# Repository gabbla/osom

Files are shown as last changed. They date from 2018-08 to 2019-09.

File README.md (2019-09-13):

# **Open speedomenter** **WIP**

**OSOM** (read as _ˈôsəm_) is the acronym of Open Speedometer.

## Architecture
The new architecture is the following:

Clinet <==BLE==> Master <==2.4GHz==> Slave

where:
- Master: CC2541 <==UART==> PIC <==SPI==> nRF24L01+
- Slave:  PIC <==SPI==> nRF24L01+

The client is a device that must be compatible with BLE (Bluetooth 4.x).

The CC2541 (aka NP, aka Network Processor) will run a standard firmware that is in charge of providing a bluetooth connection to the PIC.

Master and Slave will exchange messages over a custom, light-weight, protocol.

## Specifications

- Microcontroller: PIC32MX274F256D @72MHz (TODO verify)
- Communication:
	- Bluetooth (master only): HM10 Bluetooth 4.2 Low Energy
	- Wireless: nRF24L01+ @2.4GHz
- Power: 
	- LiPo 1s Battery, 1200/2000 mAh (not choosen yet)
	- 5V provided by micro USB, 500 mA MAX
- Sensor: custom made 650nm modulated laser sensor 
- Laser source: Red diode laser, 650nm @5mW

## PIC PIN assignment

### Bluetooth (master only)

PIN|I/O|PPS|Function|Note
--|--|--|--|--|
6|IN|RPB2|U1RX|PIC <== NP
7|OUT|RPB3|U1TX|PIC ==> NP

### nRF24L01+

PIN|I/O|PPS|Function|Note
--|--|--|--|--|
21|IN|RPB10|INT1|Interrupt generated by nRF24L01+
22|OUT|RPB11|SDO2|
23|OUT|-|CS|RB12
24|IN|RPB13|SDI2|
25|OUT|-|CE|RB14
26|OUT|RPB15|SCK2|

### Debug

PIN|I/O|PPS|Function|Note
--|--|--|--|--|
4|OUT|RPB0|U2TX|PIC ==> PC
5|IN|RPB1|U2RX|PIC <== PC

USB will be available too, with at least a _comunication device class_ (CDC) enumeration. 

### Sensing

PIN|I/O|PPS|Function|Note
--|--|--|--|--|
16|IN|-|INT0|Left IN Interrupt
11|IN|RPB4|INT4|Right IN Interrupt

### Battery Charger

New PIC analisys required

### LEDs

Analisys required. 

**Note**
1. Master only: an extra LED from CC2541 indicates the BT connection status.
2. From the battery charger an extra LED indicates che charging status.

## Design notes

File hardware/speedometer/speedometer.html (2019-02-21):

Partlist exported from /home/italia.texa.org/gzampieri/projects/speedometer/hardware/speedometer/speedometer.sch at 21/02/19 17:55

Qty | Value | Device | Package | Parts | Description | ALLIED_NUMBER | ARROW_PART_NUMBER | ARROW_PRICE-STOCK | ARROW_PRICE/STOCK | DESCRIPTION | HEIGHT | MANUFACTURER_NAME | MANUFACTURER_PART_NUMBER | MF | MPN | OC_FARNELL | OC_NEWARK | RS | RS_PART_NUMBER | RS_PRICE-STOCK | RS_PRICE/STOCK | SPICEPREFIX | TP_SIGNAL_NAME
4 | | C-EUC0402K | C0402K | C18, C21, C22, C23 | CAPACITOR, European symbol | | | | | | | | | | | | | | | | | C
3 | | LED3MM | LED3MM | LED1, LED3, LED4 | LED
2 | | LEDCHIP-LED0805 | CHIP-LED0805 | LED5, LED6 | LED
1 | | LEDCHIPLED_0805 | CHIPLED_0805 | LED2 | LED
1 | | MA06-1 | MA06-1 | SV1 | PIN HEADER | | | | | | | | | | | unknown | unknown
4 | | MUN2214T1-NPN_DRIVER-SC59-BEC | SC59-BEC | T1, T2, T3, T4 | NPN Bias Resistor Transistor
1 | | PINHD-1X3 | 1X03 | JP1 | PIN HEADER
1 | | R-US_R0603 | R0603 | R17 | RESISTOR, American symbol | | | | | | | | | | | | | | | | | R
2 | 0 | R-US_R0402 | R0402 | R21, R22 | RESISTOR, American symbol | | | | | | | | | | | | | | | | | R
2 | 100 | R-US_R0603 | R0603 | R23, R24 | RESISTOR, American symbol | | | | | | | | | | | | | | 740-8978 | | | R
2 | 100k | R-US_R0603 | R0603 | R15, R20 | RESISTOR, American symbol | | | | | | | | | | | | | | | | | R
9 | 100n | C-EUC0603K | C0603K | C1, C2, C4, C5, C6, C7, C24, C27, C28 | CAPACITOR, European symbol | | | | | | | | | | | | | | | | | C
1 | 10104111-0001LF | 10104111-0001LF | MICRO_USB_A/B_TYPE_RECEPTACLE | J1 | FCI Right Angle SMT Female Type AB Version 2.0 Micro USB Connector, 100 V ac, 1.8A | 70236825 | | | | FCI Right Angle SMT Female Type AB Version 2.0 Micro USB Connector, 100 V ac, 1.8A | mm | FCI | 10104111-0001LF | | | | | | 1622014
7 | 10k | R-US_R0603 | R0603 | R4, R5, R12, R13, R14, R28, R35 | RESISTOR, American symbol | | | | | | | | | | | | | | | | | R
1 | 10m | R-US_R2512 | R2512 | R11 | RESISTOR, American symbol | | | | | | | | | | | | | 693-4381 | | | | R
1 | 10n | C-EUC0603K | C0603K | C13 | CAPACITOR, European symbol | | | | | | | | | | | | | | | | | C
10 | 10u | C-EUC0805K | C0805K | C3, C10, C11, C12, C25, C26, C29, C30, C31, C32 | CAPACITOR, European symbol | | | | | | | | | | | | | | | | | C
1 | 1k | R-US_R0603 | R0603 | R3 | RESISTOR, American symbol | | | | | | | | | | | | | | | | | R
5 | 1k5 | R-US_R0603 | R0603 | R1, R2, R16, R30, R36 | RESISTOR, American symbol | | | | | | | | | | | | | | | | | R
2 | 1n | C-EUC0603K | C0603K | C14, C15 | CAPACITOR, European symbol | | | | | | | | | | | | | | | | | C
1 | 1p | C-EUC0402K | C0402K | C20 | CAPACITOR, European symbol | | | | | | | | | | | | | | | | | C
1 | 1u | C-EUC0603K | C0603K | C8 | CAPACITOR, European symbol | | | | | | | | | | | | | | | | | C
1 | 22k | R-US_R0603 | R0603 | R19 | RESISTOR, American symbol | | | | | | | | | | | | | | | | | R
1 | 24LC024ST | 24LC024ST | TSSOP8 | IC9 | Serial EEPROM | | | | | | | | | | 24LC024H-I/ST | 1659745 | 77M3584
1 | 2n2 | C-EUC0402K | C0402K | C17 | CAPACITOR, European symbol | | | | | | | | | | | | | | | | | C
1 | 2n7 | INDUCTOR | C0402K | L2
1 | 33n | C-EUC0402K | C0402K | C16 | CAPACITOR, European symbol | | | | | | | | | | | | | | | | | C
1 | 3n9 | INDUCTOR | C0402K | L3
2 | 470 | R-US_R0603 | R0603 | R9, R10 | RESISTOR, American symbol | | | | | | | | | | | | | | | | | R
1 | 470n | C-EUC0603K | C0603K | C9 | CAPACITOR, European symbol | | | | | | | | | | | | | | | | | C
3 | 4k7 | R-US_R0603 | R0603 | R6, R7, R8 | RESISTOR, American symbol | | | | | | | | | | | | | | | | | R
1 | 4p7 | C-EUC0402K | C0402K | C19 | CAPACITOR, European symbol | | | | | | | | | | | | | | | | | C
1 | 74LVC1G32SE-7 | 74LVC1G32SE-7 | SOT353 | IC13
1 | 887 | R-US_R0603 | R0603 | R18 | RESISTOR, American symbol | | | | | | | | | | | | | 708-6111 | | | | R
1 | 8n2 | INDUCTOR | C0402K | L1
1 | BAT | B2B-PH-SM4-TB(LF)(SN) | B2B-PH-SM4-TB | J2 | Wire-To-Board Connector, PH Series, 2 Contacts, Header, 2 mm, Surface Mount, 1 Rows | | | | | Wire-To-Board Connector, PH Series, 2 Contacts, Header, 2 mm, Surface Mount, 1 Rows | mm | JST (JAPAN SOLDERLESS TERMINALS) | B2B-PH-SM4-TB(LF)(SN) | | | | | | 6881325P
1 | BQ24075RGTT | BQ24075RGTT | QFN50P300X300X80-17N | IC6 | 1.5A Li-Ion Charger, Power-Path VQFN16EP BQ24075RGTT, Battery Charge Controller, Lithium-Ion, 4500mA, 16-Pin QFN | | BQ24075RGTT | | https://www.arrow.com/en/products/bq24075rgtt/texas-instruments | 1.5A Li-Ion Charger, Power-Path VQFN16EP BQ24075RGTT, Battery Charge Controller, Lithium-Ion, 4500mA, 16-Pin QFN | 0.8mm | Texas Instruments | BQ24075RGTT | | | | | | 8175815P | | http://uk.rs-online.com/web/p/products/8175815P
1 | BQ27441DRZR-G1A | BQ27441DRZR-G1A | BQ27441DRZRG1A | IC5 | System-Side Impedance Track Battery Fuel (Gas) Gauge | | BQ27441DRZR-G1A | https://www.arrow.com/en/products/bq27441drzr-g1a/texas-instruments | | System-Side Impedance Track Battery Fuel (Gas) Gauge | mm | Texas Instruments | BQ27441DRZR-G1A
1 | CONUFL001-SMD-T | CONUFL001-SMD-T | CONUFL001-SMD | J3 | RF Connectors / Coaxial Connectors T&R U.FL Straight Surface Mount Jack | | CONUFL001-SMD-T | | | RF Connectors / Coaxial Connectors T&R U.FL Straight Surface Mount Jack | mm | Linx Technologies | CONUFL001-SMD-T
1 | CSTCE16M0V53-R0 | CSTCE12M0G15L99-R0 | CSTCE_G | IC8 | CSTCE12M0G15L99-R0, Ceramic Resonator, 12MHz Shear 33pF, 3-Pin SMT, 3.2 x 1.3 x 0.7mm | | CSTCE12M0G15L99-R0 | | https://www.arrow.com/en/products/cstce12m0g15l99-r0/murata-manufacturing | CSTCE12M0G15L99-R0, Ceramic Resonator, 12MHz Shear 33pF, 3-Pin SMT, 3.2 x 1.3 x 0.7mm | mm | Murata Electronics | CSTCE12M0G15L99-R0 | | | | | | 7926527P | | http://uk.rs-online.com/web/p/products/7926527P
1 | CSTCE8M00G55-R0 | CSTCE12M0G15L99-R0 | CSTCE_G | IC3 | CSTCE12M0G15L99-R0, Ceramic Resonator, 12MHz Shear 33pF, 3-Pin SMT, 3.2 x 1.3 x 0.7mm | | CSTCE12M0G15L99-R0 | | https://www.arrow.com/en/products/cstce12m0g15l99-r0/murata-manufacturing | CSTCE12M0G15L99-R0, Ceramic Resonator, 12MHz Shear 33pF, 3-Pin SMT, 3.2 x 1.3 x 0.7mm | mm | Murata Electronics | CSTCE12M0G15L99-R0 | | | | | | 7926527P | | http://uk.rs-online.com/web/p/products/7926527P
1 | HM-11 | HM-11 | HM-11 | IC4 | JNHuaMao HM-11 Bluetooth 4.0 Transceiver
1 | Left | B2B-XH-A(LF)(SN) | SHDR2W64P0X250_1X2_740X575X700 | J7 | JST XH Series, 2.5mm Pitch 2 Way 1 Row Straight PCB Header, Solder Termination, 3A | | B2B-XH-A(LF)(SN) | | https://www.arrow.com/en/products/b2b-xh-a-lf-sn/jst-manufacturing | JST XH Series, 2.5mm Pitch 2 Way 1 Row Straight PCB Header, Solder Termination, 3A | 7mm | JST (JAPAN SOLDERLESS TERMINALS) | B2B-XH-A(LF)(SN) | | | | | | 1667312 | | http://uk.rs-online.com/web/p/products/1667312
1 | Left_sens | B4B-XH-A(LF)(SN) | SHDR4W64P0X250_1X4_1240X575X70 | J6 | XH-2.5mm Header top entry 4 way JST XH Series, Series Number B4B, 2.5mm Pitch 4 Way 1 Row Straight PCB Header, Solder Termination, 3A | | B4B-XH-A(LF)(SN) | | https://www.arrow.com/en/products/b4b-xh-a-lf-sn/jst-manufacturing | XH-2.5mm Header top entry 4 way JST XH Series, Series Number B4B, 2.5mm Pitch 4 Way 1 Row Straight PCB Header, Solder Termination, 3A | 7mm | JST (JAPAN SOLDERLESS TERMINALS) | B4B-XH-A(LF)(SN) | | | | | | 1724913 | | http://uk.rs-online.com/web/p/products/1724913 | E
1 | M310210 | M310210 | M310210 | ANT1
1 | MAX16054AZT+T | MAX16054AZT+T | SOT95P275X110-6N | IC10 | On Off Controller, Debounce, 15kV ESD MAX16054AZT+T, Voltage Supervisor No Push Button Controller 6-Pin SOT-23 | | MAX16054AZT+T | | http://uk.rs-online.com/web/p/products/9237416 | On Off Controller, Debounce, 15kV ESD MAX16054AZT+T, Voltage Supervisor No Push Button Controller 6-Pin SOT-23 | 1.1mm | Maxim Integrated | MAX16054AZT+T | | | | | | 9237416 | | http://uk.rs-online.com/web/p/products/9237416
1 | NRF24L01P-T | NRF24L01P-T | QFN50P400X400X95-21N | IC7 | RF Transceiver IC 2.4GHz ISM Band QFN20 Nordic Semiconductor NRF24L01P-T, RF Transceiver 2400MHz to 2483.5MHz 1.9 3.6 V 20-Pin QFN | | nRF24L01P-T | | https://www.arrow.com/en/products/nrf24l01p-t/nordic-semiconductor | RF Transceiver IC 2.4GHz ISM Band QFN20 Nordic Semiconductor NRF24L01P-T, RF Transceiver 2400MHz to 2483.5MHz 1.9 3.6 V 20-Pin QFN | 0.95mm | Nordic Semiconductor | nRF24L01P-T | | | | | | 8855748P | | http://uk.rs-online.com/web/p/products/8855748P
1 | PIC32MX274F256DT-I_PT | PIC32MX274F256DT-I_PT | QFP80P1200X1200X120-44N | IC1 | 32-bit Microcontrollers - MCU 256KB Flash, 64KB RAM, 10-Bit ADC, UART, SPI/I2S, I2C + VBATT Pin, USB | | PIC32MX274F256DT-I/PT | | | 32-bit Microcontrollers - MCU 256KB Flash, 64KB RAM, 10-Bit ADC, UART, SPI/I2S, I2C + VBATT Pin, USB | 1.2mm | Microchip | PIC32MX274F256DT-I/PT
1 | PTS645VJM61LFS | PTS645VJM61LFS | PTS645VJM61LFS | S1 | Tactile Switches Tact | | PTS645VJM61LFS | | | Tactile Switches Tact | 7mm | C & K COMPONENTS | PTS645VJM61LFS
1 | Right | B2B-XH-A(LF)(SN) | SHDR2W64P0X250_1X2_740X575X700 | J5 | JST XH Series, 2.5mm Pitch 2 Way 1 Row Straight PCB Header, Solder Termination, 3A | | B2B-XH-A(LF)(SN) | | https://www.arrow.com/en/products/b2b-xh-a-lf-sn/jst-manufacturing | JST XH Series, 2.5mm Pitch 2 Way 1 Row Straight PCB Header, Solder Termination, 3A | 7mm | JST (JAPAN SOLDERLESS TERMINALS) | B2B-XH-A(LF)(SN) | | | | | | 1667312 | | http://uk.rs-online.com/web/p/products/1667312
1 | Right_sens | B4B-XH-A(LF)(SN) | SHDR4W64P0X250_1X4_1240X575X70 | J4 | XH-2.5mm Header top entry 4 way JST XH Series, Series Number B4B, 2.5mm Pitch 4 Way 1 Row Straight PCB Header, Solder Termination, 3A | | B4B-XH-A(LF)(SN) | | https://www.arrow.com/en/products/b4b-xh-a-lf-sn/jst-manufacturing | XH-2.5mm Header top entry 4 way JST XH Series, Series Number B4B, 2.5mm Pitch 4 Way 1 Row Straight PCB Header, Solder Termination, 3A | 7mm | JST (JAPAN SOLDERLESS TERMINALS) | B4B-XH-A(LF)(SN) | | | | | | 1724913 | | http://uk.rs-online.com/web/p/products/1724913
1 | SN65220DBVRG4 | SN65220DBVRG4 | SOT95P280X145-6N | IC2 | ESD Suppressors / TVS Diodes Sngl Port Transient Suppressor | | SN65220DBVRG4 | | https://www.arrow.com/en/products/sn65220dbvrg4/texas-instruments | ESD Suppressors / TVS Diodes Sngl Port Transient Suppressor | 1.45mm | Texas Instruments | SN65220DBVRG4
2 | SN74AHC1G08DBVR | SN74AHC1G08DBVR | SOT95P280X145-5N | U1, U2 | Texas Instruments SN74AHC1G08DBVR, 2-Input AND Logic Gate, 2 5.5 V, 5-Pin SOT-23 | | SN74AHC1G08DBVR | https://www.arrow.com/en/products/sn74ahc1g08dbvr/texas-instruments | | Texas Instruments SN74AHC1G08DBVR, 2-Input AND Logic Gate, 2 5.5 V, 5-Pin SOT-23 | 1.45mm | Texas Instruments | SN74AHC1G08DBVR | | | | | | 1218343 | http://uk.rs-online.com/web/p/products/1218343
1 | TPB1,27 | TPB1,27 | B1,27 | TP12 | Test pad | | | | | | | | | | | | | | | | | | BT_KEY
1 | TPB1,27 | TPB1,27 | B1,27 | TP11 | Test pad | | | | | | | | | | | | | | | | | | BT_RST
1 | TPB1,27 | TPB1,27 | B1,27 | TP10 | Test pad | | | | | | | | | | | | | | | | | | BT_RX
1 | TPB1,27 | TPB1,27 | B1,27 | TP9 | Test pad | | | | | | | | | | | | | | | | | | BT_TX
1 | TPB1,27 | TPB1,27 | B1,27 | TP17 | Test pad | | | | | | | | | | | | | | | | | | TP_!CHG
1 | TPB1,27 | TPB1,27 | B1,27 | TP16 | Test pad | | | | | | | | | | | | | | | | | | TP_!PGOOD
1 | TPB1,27 | TPB1,27 | B1,27 | TP22 | Test pad | | | | | | | | | | | | | | | | | | TP_3V3
1 | TPB1,27 | TPB1,27 | B1,27 | TP23 | Test pad | | | | | | | | | | | | | | | | | | TP_5V
1 | TPB1,27 | TPB1,27 | B1,27 | TP13 | Test pad | | | | | | | | | | | | | | | | | | TP_BAT
1 | TPB1,27 | TPB1,27 | B1,27 | TP14 | Test pad | | | | | | | | | | | | | | | | | | TP_BAT2
1 | TPB1,27 | TPB1,27 | B1,27 | TP18 | Test pad | | | | | | | | | | | | | | | | | | TP_GND
2 | TPB1,27 | TPB1,27 | B1,27 | TP25, TP26 | Test pad | | | | | | | | | | | | | | | | | | TP_L_DX
1 | TPB1,27 | TPB1,27 | B1,27 | TP8 | Test pad | | | | | | | | | | | | | | | | | | TP_NRF_CE
1 | TPB1,27 | TPB1,27 | B1,27 | TP6 | Test pad | | | | | | | | | | | | | | | | | | TP_NRF_CS
1 | TPB1,27 | TPB1,27 | B1,27 | TP5 | Test pad | | | | | | | | | | | | | | | | | | TP_NRF_IRQ
1 | TPB1,27 | TPB1,27 | B1,27 | TP1 | Test pad | | | | | | | | | | | | | | | | | | TP_SCL
1 | TPB1,27 | TPB1,27 | B1,27 | TP2 | Test pad | | | | | | | | | | | | | | | | | | TP_SDA
1 | TPB1,27 | TPB1,27 | B1,27 | TP7 | Test pad | | | | | | | | | | | | | | | | | | TP_SPI1_SCK
1 | TPB1,27 | TPB1,27 | B1,27 | TP4 | Test pad | | | | | | | | | | | | | | | | | | TP_SPI1_SDI
1 | TPB1,27 | TPB1,27 | B1,27 | TP3 | Test pad | | | | | | | | | | | | | | | | | | TP_SPI1_SDO
1 | TPB1,27 | TPB1,27 | B1,27 | TP24 | Test pad | | | | | | | | | | | | | | | | | | TP_SYS_EN
1 | TPB1,27 | TPB1,27 | B1,27 | TP21 | Test pad | | | | | | | | | | | | | | | | | | TP_SYS_EN_MAX
1 | TPB1,27 | TPB1,27 | B1,27 | TP20 | Test pad | | | | | | | | | | | | | | | | | | TP_SYS_EN_PIC
1 | TPB1,27 | TPB1,27 | B1,27 | TP19 | Test pad | | | | | | | | | | | | | | | | | | TP_VCCINT
1 | TPB1,27 | TPB1,27 | B1,27 | TP15 | Test pad | | | | | | | | | | | | | | | | | | TP_VUSB
1 | TPS63001DRCT | TPS63000DRCT | SON50P300X300X100-11N | IC11 | TPS63000DRCT Buck/Boost Converter, 1.2A, Adjustable, 1.2 5.5 V, 1500 kHz, 10-Pin SON EP | | TPS63000DRCT | | https://www.arrow.com/en/products/tps63000drct/texas-instruments | TPS63000DRCT Buck/Boost Converter, 1.2A, Adjustable, 1.2 5.5 V, 1500 kHz, 10-Pin SON EP | 1mm | Texas Instruments | TPS63000DRCT | | | | | | 0389334P | | http://uk.rs-online.com/web/p/products/0389334P
1 | TPS63002DRCT | TPS63000DRCT | SON50P300X300X100-11N | IC12 | TPS63000DRCT Buck/Boost Converter, 1.2A, Adjustable, 1.2 5.5 V, 1500 kHz, 10-Pin SON EP | | TPS63000DRCT | | https://www.arrow.com/en/products/tps63000drct/texas-instruments | TPS63000DRCT Buck/Boost Converter, 1.2A, Adjustable, 1.2 5.5 V, 1500 kHz, 10-Pin SON EP | 1mm | Texas Instruments | TPS63000DRCT | | | | | | 0389334P | | http://uk.rs-online.com/web/p/products/0389334P
2 | TSW-102-07-G-S | TSW-102-07-G-S | TSW-102-XX-G-S | X1, X2 | THROUGH-HOLE .025" SQ POST HEADER | | | | | | | | | Samtec Inc. | TSW-102-07-G-S
2 | VLF4012AT-2R2M1R5 | LPS3015-222MRB | LPS3015 | L4, L5 | COILCRAFT - LPS3015-222MRB - INDUCTOR, SHLD, 2.2UH, 20%, 1.1A, SMD | | LPS3015-222MRB | | | COILCRAFT - LPS3015-222MRB - INDUCTOR, SHLD, 2.2UH, 20%, 1.1A, SMD | mm | COILCRAFT | LPS3015-222MRB | | | | | | 644-1952

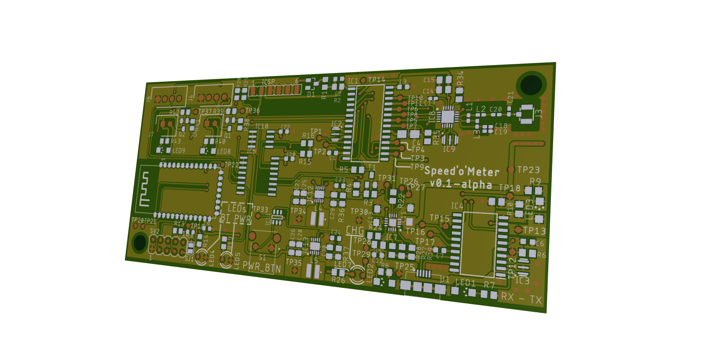
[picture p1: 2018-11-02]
images/speedometer_v_0_1_alpha.png

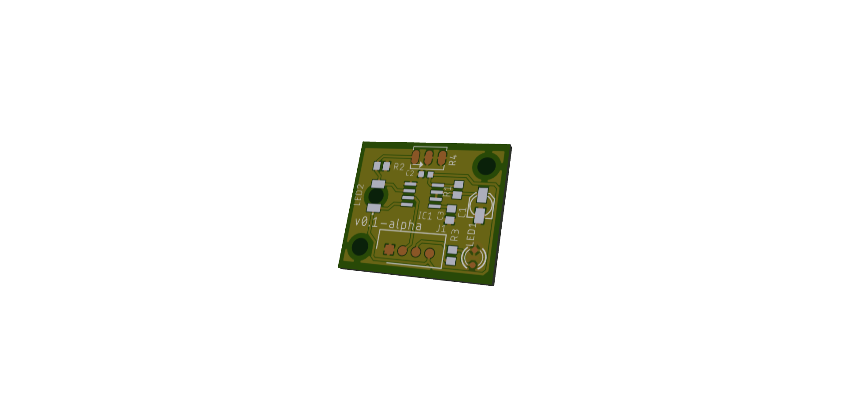
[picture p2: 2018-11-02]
images/laser_sensor_v_0_1_alpha.png

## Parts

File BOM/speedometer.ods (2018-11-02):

Qty | Value | Device | Package | Parts | Description | ALLIED_NUMBER | ALLIED_PRICE/STOCK | ARROW_PART_NUMBER | ARROW_PRICE/STOCK | DESCRIPTION | HEIGHT | MANUFACTURER_NAME | MANUFACTURER_PART_NUMBER | MF | MPN | OC_FARNELL | OC_NEWARK | RS | RS_PART_NUMBER | RS_PRICE/STOCK | SPICEPREFIX | TP_SIGNAL_NAME
1 | microUSB | 10104111-0001LF | MICRO_USB_A/B_TYPE_RECEPTACLE | J1 | FCI Right Angle SMT Female Type AB Version 2.0 Micro USB Connector, 100 V ac, 1.8A | 70236825 |  |  |  | FCI Right Angle SMT Female Type AB Version 2.0 Micro USB Connector, 100 V ac, 1.8A | mm | FCI | 10104111-0001LF |  |  |  |  |  | 1622014
1 | 24LC024SN | 24LC024SN | SO-08 | IC10 | Serial EEPROM |  |  |  |  |  |  |  |  | MICROCHIP | 24LC024/SN | 1659744 | 92C7092
1 | BAT | B2B-PH-SM4-TB(LF)(SN) | B2B-PH-SM4-TB | J2 | Wire-To-Board Connector, PH Series, 2 Contacts, Header, 2 mm, Surface Mount, 1 Rows |  |  |  |  | Wire-To-Board Connector, PH Series, 2 Contacts, Header, 2 mm, Surface Mount, 1 Rows | mm | JST (JAPAN SOLDERLESS TERMINALS) | B2B-PH-SM4-TB(LF)(SN) |  |  |  |  |  | 6881325P
1 | Left | B2B-XH-A(LF)(SN) | SHDR2W64P0X250_1X2_740X575X700 | J7 | JST XH Series, 2.5mm Pitch 2 Way 1 Row Straight PCB Header, Solder Termination, 3A |  |  | B2B-XH-A(LF)(SN) | https://www.arrow.com/en/products/b2b-xh-a-lf-sn/jst-manufacturing | JST XH Series, 2.5mm Pitch 2 Way 1 Row Straight PCB Header, Solder Termination, 3A | 7mm | JST (JAPAN SOLDERLESS TERMINALS) | B2B-XH-A(LF)(SN) |  |  |  |  |  | 1667312 | http://uk.rs-online.com/web/p/products/1667312 | B
1 | Right | B2B-XH-A(LF)(SN) | SHDR2W64P0X250_1X2_740X575X700 | J5 | JST XH Series, 2.5mm Pitch 2 Way 1 Row Straight PCB Header, Solder Termination, 3A |  |  | B2B-XH-A(LF)(SN) | https://www.arrow.com/en/products/b2b-xh-a-lf-sn/jst-manufacturing | JST XH Series, 2.5mm Pitch 2 Way 1 Row Straight PCB Header, Solder Termination, 3A | 7mm | JST (JAPAN SOLDERLESS TERMINALS) | B2B-XH-A(LF)(SN) |  |  |  |  |  | 1667312 | http://uk.rs-online.com/web/p/products/1667312
1 | Left_sens | B4B-XH-A(LF)(SN) | SHDR4W64P0X250_1X4_1240X575X70 | J6 | XH-2.5mm Header top entry 4 way JST XH Series, Series Number B4B, 2.5mm Pitch 4 Way 1 Row Straight PCB Header, Solder Termination, 3A |  |  | B4B-XH-A(LF)(SN) | https://www.arrow.com/en/products/b4b-xh-a-lf-sn/jst-manufacturing | XH-2.5mm Header top entry 4 way JST XH Series, Series Number B4B, 2.5mm Pitch 4 Way 1 Row Straight PCB Header, Solder Termination, 3A | 7mm | JST (JAPAN SOLDERLESS TERMINALS) | B4B-XH-A(LF)(SN) |  |  |  |  |  | 1724913 | http://uk.rs-online.com/web/p/products/1724913 | E
1 | Right_sens | B4B-XH-A(LF)(SN) | SHDR4W64P0X250_1X4_1240X575X70 | J4 | XH-2.5mm Header top entry 4 way JST XH Series, Series Number B4B, 2.5mm Pitch 4 Way 1 Row Straight PCB Header, Solder Termination, 3A |  |  | B4B-XH-A(LF)(SN) | https://www.arrow.com/en/products/b4b-xh-a-lf-sn/jst-manufacturing | XH-2.5mm Header top entry 4 way JST XH Series, Series Number B4B, 2.5mm Pitch 4 Way 1 Row Straight PCB Header, Solder Termination, 3A | 7mm | JST (JAPAN SOLDERLESS TERMINALS) | B4B-XH-A(LF)(SN) |  |  |  |  |  | 1724913 | http://uk.rs-online.com/web/p/products/1724913
1 | BAT54 | BAT54 | SOT23 | D1 | Schottky Diodes
2 | BC817 | BC817-16LT1SMD | SOT23-BEC | Q1, Q3 | NPN Transistor
2 | BC817 | BC817-16LT1SMD | SOT23-BEC | Q2, Q4 | NPN Transistor |  |  |  |  |  |  |  |  |  |  |  |  |  |  |  | Q
1 | BC817-16LT1SMD | BC817-16LT1SMD | SOT23-BEC | T1 | NPN Transistor
1 | BQ24075RGTT | BQ24075RGTT | QFN50P300X300X80-17N | IC7 | 1.5A Li-Ion Charger, Power-Path VQFN16EP BQ24075RGTT, Battery Charge Controller, Lithium-Ion, 4500mA, 16-Pin QFN |  |  | BQ24075RGTT | https://www.arrow.com/en/products/bq24075rgtt/texas-instruments | 1.5A Li-Ion Charger, Power-Path VQFN16EP BQ24075RGTT, Battery Charge Controller, Lithium-Ion, 4500mA, 16-Pin QFN | 0.8mm | Texas Instruments | BQ24075RGTT |  |  |  |  |  | 8175815P | http://uk.rs-online.com/web/p/products/8175815P
1 | 1p | C-EUC0402K | C0402K | C21 | CAPACITOR, European symbol |  |  |  |  |  |  |  |  |  |  |  |  |  |  |  | C
1 | 1p5 | C-EUC0402K | C0402K | C20 | CAPACITOR, European symbol |  |  |  |  |  |  |  |  |  |  |  |  |  |  |  | C
1 | 2n2 | C-EUC0402K | C0402K | C18 | CAPACITOR, European symbol |  |  |  |  |  |  |  |  |  |  |  |  |  |  |  | C
1 | 33n | C-EUC0402K | C0402K | C17 | CAPACITOR, European symbol |  |  |  |  |  |  |  |  |  |  |  |  |  |  |  | C
1 | 4p7 | C-EUC0402K | C0402K | C19 | CAPACITOR, European symbol |  |  |  |  |  |  |  |  |  |  |  |  |  |  |  | C
12 | 100n | C-EUC0603K | C0603K | C1, C2, C3, C6, C7, C8, C9, C10, C12, C22, C23, C24 | CAPACITOR, European symbol |  |  |  |  |  |  |  |  |  |  |  |  |  |  |  | C
1 | 10n | C-EUC0805K | C0805K | C14 | CAPACITOR, European symbol |  |  |  |  |  |  |  |  |  |  |  |  |  |  |  | C
6 | 10u | C-EUC0805K | C0805K | C25, C26, C27, C28, C29, C30 | CAPACITOR, European symbol |  |  |  |  |  |  |  |  |  |  |  |  |  |  |  | C
1 | 1n | C-EUC0805K | C0805K | C15 | CAPACITOR, European symbol |  |  |  |  |  |  |  |  |  |  |  |  |  |  |  | C
1 | 4u7 | C-EUC0805K | C0805K | C5 | CAPACITOR, European symbol |  |  |  |  |  |  |  |  |  |  |  |  |  |  |  | C
1 | CONUFL001-SMD-T | CONUFL001-SMD-T | CONUFL001-SMD | J3 | RF Connectors / Coaxial Connectors T&R U.FL Straight Surface Mount Jack |  |  | CONUFL001-SMD-T |  | RF Connectors / Coaxial Connectors T&R U.FL Straight Surface Mount Jack | mm | Linx Technologies | CONUFL001-SMD-T
1 | 10u | CPOL-EUA/3216-18W | A/3216-18W | C4 | POLARIZED CAPACITOR, European symbol |  |  |  |  |  |  |  |  |  |  |  |  | 501-9324 |  |  | C
2 | 4u7 | CPOL-EUSMCA | SMC_A | C11, C13 | POLARIZED CAPACITOR, European symbol |  |  |  |  |  |  |  |  |  |  |  |  |  |  |  | C
1 | CSTCE12M0G15L99-R0 | CSTCE12M0G15L99-R0 | CSTCE_G | IC3 | CSTCE12M0G15L99-R0, Ceramic Resonator, 12MHz Shear 33pF, 3-Pin SMT, 3.2 x 1.3 x 0.7mm |  |  | CSTCE12M0G15L99-R0 | https://www.arrow.com/en/products/cstce12m0g15l99-r0/murata-manufacturing | CSTCE12M0G15L99-R0, Ceramic Resonator, 12MHz Shear 33pF, 3-Pin SMT, 3.2 x 1.3 x 0.7mm | mm | Murata Electronics | CSTCE12M0G15L99-R0 |  |  |  |  |  | 7926527P | http://uk.rs-online.com/web/p/products/7926527P
1 | CSTCE16M0V53-R0 | CSTCE12M0G15L99-R0 | CSTCE_G | IC9 | CSTCE12M0G15L99-R0, Ceramic Resonator, 12MHz Shear 33pF, 3-Pin SMT, 3.2 x 1.3 x 0.7mm |  |  | CSTCE12M0G15L99-R0 | https://www.arrow.com/en/products/cstce12m0g15l99-r0/murata-manufacturing | CSTCE12M0G15L99-R0, Ceramic Resonator, 12MHz Shear 33pF, 3-Pin SMT, 3.2 x 1.3 x 0.7mm | mm | Murata Electronics | CSTCE12M0G15L99-R0 |  |  |  |  |  | 7926527P | http://uk.rs-online.com/web/p/products/7926527P
1 | CSTCE8M00G55-R0 | CSTCE12M0G15L99-R0 | CSTCE_G | IC2 | CSTCE12M0G15L99-R0, Ceramic Resonator, 12MHz Shear 33pF, 3-Pin SMT, 3.2 x 1.3 x 0.7mm |  |  | CSTCE12M0G15L99-R0 | https://www.arrow.com/en/products/cstce12m0g15l99-r0/murata-manufacturing | CSTCE12M0G15L99-R0, Ceramic Resonator, 12MHz Shear 33pF, 3-Pin SMT, 3.2 x 1.3 x 0.7mm | mm | Murata Electronics | CSTCE12M0G15L99-R0 |  |  |  |  |  | 7926527P | http://uk.rs-online.com/web/p/products/7926527P
1 |  | FE06-1 | FE06 | ICSP | FEMALE HEADER |  |  |  |  |  |  |  |  |  |  | unknown | unknown
1 | HM-10 | HM-10 | HM-10 | U1
1 | 2n7 | INDUCTOR | C0402K | L3
1 | 3n9 | INDUCTOR | C0402K | L2
1 | 8n2 | INDUCTOR | C0402K | L1
1 |  | LED3MM | LED3MM | LED7 | LED
1 | Blue | LED3MM | LED3MM | LED4 | LED
1 | Red | LED3MM | LED3MM | LED5 | LED
1 |  | LEDCHIPLED_1206 | CHIPLED_1206 | LED8 | LED
1 |  | LEDCHIPLED_1206 | CHIPLED_1206 | LED9 | LED |  |  |  |  |  |  |  |  |  |  |  |  |  |  |  | L
1 | Blue | LEDCHIPLED_1206 | CHIPLED_1206 | LED3 | LED
1 | Green | LEDCHIPLED_1206 | CHIPLED_1206 | LED1 | LED
1 | Red | LEDCHIPLED_1206 | CHIPLED_1206 | LED2 | LED
1 |  | MA05-2 | MA05-2 | SV2 | PIN HEADER |  |  |  |  |  |  |  |  |  |  | unknown | unknown
1 | MAX16054AZT+T | MAX16054AZT+T | SOT95P275X110-6N | IC11 | On Off Controller, Debounce, 15kV ESD MAX16054AZT+T, Voltage Supervisor No Push Button Controller 6-Pin SOT-23 |  |  | MAX16054AZT+T | http://uk.rs-online.com/web/p/products/9237416 | On Off Controller, Debounce, 15kV ESD MAX16054AZT+T, Voltage Supervisor No Push Button Controller 6-Pin SOT-23 | 1.1mm | Maxim Integrated | MAX16054AZT+T |  |  |  |  |  | 9237416 | http://uk.rs-online.com/web/p/products/9237416
1 | MCP2200-I_SO | MCP2200-I_SO | SOIC127P1030X265-20N | IC4 | USB 2.0 to serial UART converter w/ GPIO | 70047463 | http://www.alliedelec.com/microchip-technology-inc-mcp2200-i-so/70047463/ | MCP2200-I/SO | https://www.arrow.com/en/products/mcp2200-iso/microchip-technology | USB 2.0 to serial UART converter w/ GPIO | 2.65mm | Microchip | MCP2200-I/SO |  |  |  |  |  | 6988993P | http://uk.rs-online.com/web/p/products/6988993P
1 | NRF24L01P-T | NRF24L01P-T | QFN50P400X400X95-21N | IC8 | RF Transceiver IC 2.4GHz ISM Band QFN20 Nordic Semiconductor NRF24L01P-T, RF Transceiver 2400MHz to 2483.5MHz 1.9 3.6 V 20-Pin QFN |  |  | nRF24L01P-T | https://www.arrow.com/en/products/nrf24l01p-t/nordic-semiconductor | RF Transceiver IC 2.4GHz ISM Band QFN20 Nordic Semiconductor NRF24L01P-T, RF Transceiver 2400MHz to 2483.5MHz 1.9 3.6 V 20-Pin QFN | 0.95mm | Nordic Semiconductor | nRF24L01P-T |  |  |  |  |  | 8855748P | http://uk.rs-online.com/web/p/products/8855748P
1 | PCF8574T | PCF8574T | SO16W | IC6 | I2C-Bus Remote 8-bit I/O expander |  |  |  |  |  |  |  |  |  | PCF8574T/3,512 | 1201255 | 70R6870
1 | PIC32MX110F016B-I_SO | PIC32MX110F016B-I_SO | SOIC127P1030X265-28N | IC1 | 32-bit Microcontrollers (up to 256 KB Flash and 64 KB SRAM) with Audio and Graphics Interfaces, USB, and Advanced Analog | 70452123 | http://www.alliedelec.com/microchip-technology-inc-pic32mx110f016b-i-so/70452123/ | PIC32MX110F016B-I/SO | https://www.arrow.com/en/products/pic32mx110f016b-iso/microchip-technology | 32-bit Microcontrollers (up to 256 KB Flash and 64 KB SRAM) with Audio and Graphics Interfaces, USB, and Advanced Analog | 2.65mm | Microchip | PIC32MX110F016B-I/SO
1 | PTS645VJM61LFS | PTS645VJM61LFS | PTS645VJM61LFS | S1 | Tactile Switches Tact |  |  | PTS645VJM61LFS |  | Tactile Switches Tact | 7mm | C & K COMPONENTS | PTS645VJM61LFS
1 |  | R-US_R0805 | R0805 | R17 | RESISTOR, American symbol
1 |  | R-US_R0805 | R0805 | R24 | RESISTOR, American symbol |  |  |  |  |  |  |  |  |  |  |  |  |  |  |  | R
2 | 100 | R-US_R0805 | R0805 | R36, R37 | RESISTOR, American symbol |  |  |  |  |  |  |  |  |  |  |  |  |  | 740-8978 |  | R
7 | 100k | R-US_R0805 | R0805 | R4, R18, R22, R23, R35, R39, R42 | RESISTOR, American symbol |  |  |  |  |  |  |  |  |  |  |  |  |  |  |  | R
13 | 10k | R-US_R0805 | R0805 | R1, R3, R5, R12, R13, R15, R16, R19, R20, R21, R25, R38, R41 | RESISTOR, American symbol |  |  |  |  |  |  |  |  |  |  |  |  |  |  |  | R
1 | 18k | R-US_R0805 | R0805 | R10 | RESISTOR, American symbol |  |  |  |  |  |  |  |  |  |  |  |  |  |  |  | R
1 | 1k | R-US_R0805 | R0805 | R2 | RESISTOR, American symbol |  |  |  |  |  |  |  |  |  |  |  |  |  |  |  | R
3 | 1k5 | R-US_R0805 | R0805 | R26, R40, R43 | RESISTOR, American symbol |  |  |  |  |  |  |  |  |  |  |  |  |  |  |  | R
1 | 22k | R-US_R0805 | R0805 | R34 | RESISTOR, American symbol |  |  |  |  |  |  |  |  |  |  |  |  |  |  |  | R
1 | 39k | R-US_R0805 | R0805 | R11 | RESISTOR, American symbol |  |  |  |  |  |  |  |  |  |  |  |  |  |  |  | R
1 | 4k7 | R-US_R0805 | R0805 | R6 | RESISTOR, American symbol |  |  |  |  |  |  |  |  |  |  |  |  |  |  |  | R
1 | 620 | R-US_R0805 | R0805 | R14 | RESISTOR, American symbol
3 | 620 | R-US_R0805 | R0805 | R7, R8, R9 | RESISTOR, American symbol |  |  |  |  |  |  |  |  |  |  |  |  |  |  |  | R
1 | 887 | R-US_R0805 | R0805 | R27 | RESISTOR, American symbol |  |  |  |  |  |  |  |  |  |  |  |  | 708-6111 |  |  | R
1 | TBD | R-US_R0805 | R0805 | R28 | RESISTOR, American symbol |  |  |  |  |  |  |  |  |  |  |  |  | 708-6111 |  |  | R
1 | TPS63001DRCT | TPS63000DRCT | SON50P300X300X100-11N | IC12 | TPS63000DRCT Buck/Boost Converter, 1.2A, Adjustable, 1.2 5.5 V, 1500 kHz, 10-Pin SON EP |  |  | TPS63000DRCT | https://www.arrow.com/en/products/tps63000drct/texas-instruments | TPS63000DRCT Buck/Boost Converter, 1.2A, Adjustable, 1.2 5.5 V, 1500 kHz, 10-Pin SON EP | 1mm | Texas Instruments | TPS63000DRCT |  |  |  |  |  | 0389334P | http://uk.rs-online.com/web/p/products/0389334P
1 | TPS63002DRCT | TPS63000DRCT | SON50P300X300X100-11N | IC13 | TPS63000DRCT Buck/Boost Converter, 1.2A, Adjustable, 1.2 5.5 V, 1500 kHz, 10-Pin SON EP |  |  | TPS63000DRCT | https://www.arrow.com/en/products/tps63000drct/texas-instruments | TPS63000DRCT Buck/Boost Converter, 1.2A, Adjustable, 1.2 5.5 V, 1500 kHz, 10-Pin SON EP | 1mm | Texas Instruments | TPS63000DRCT |  |  |  |  |  | 0389334P | http://uk.rs-online.com/web/p/products/0389334P
2 | VLF4012AT-2R2M1R5 | VLF4012AT-3R3M1R3 | VLF4012A | L4, L5 | Fixed Inductors 3.3uH 1.3A 4x4x1.2mm |  |  | VLF4012AT-3R3M1R3 | https://www.arrow.com/en/products/vlf4012at-3r3m1r3/tdk | Fixed Inductors 3.3uH 1.3A 4x4x1.2mm | mm | TDK | VLF4012AT-3R3M1R3 |  |  |  |  |  | 644-1952
2 | 994-LPS3015-222MRB (https://www.mouser.it/ProductDetail/994-LPS3015-222MRB)

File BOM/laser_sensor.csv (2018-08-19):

Qty | Value | Device | Package | Parts | Description | ARROW_PART_NUMBER | ARROW_PRICE/STOCK | DESCRIPTION | HEIGHT | MANUFACTURER_NAME | MANUFACTURER_PART_NUMBER | RS_PART_NUMBER | RS_PRICE/STOCK | SPICEPREFIX
1 |  | LED3MM | LED3MM | LED1 | LED
1 |  | TRIM_EU-B64Y | B64Y | R4 | POTENTIOMETER
1 | 100n | C-EUC0603K | C0603K | C2 | CAPACITOR, European symbol |  |  |  |  |  |  |  |  | C
1 | 10n | C-EUC0805K | C0805K | C3 | CAPACITOR, European symbol |  |  |  |  |  |  |  |  | C
1 | 15k | R-US_M0805 | M0805 | R2 | RESISTOR, American symbol
1 | 1M | R-US_M0805 | M0805 | R1 | RESISTOR, American symbol
1 | 1u | CPOL-EU153CLV-0405 | 153CLV-0405 | C1 | POLARIZED CAPACITOR, European symbol |  |  |  |  |  |  |  |  | C
1 | 560 | R-US_M0805 | M0805 | R3 | RESISTOR, American symbol
1 | B4B-XH-A(LF)(SN) | B4B-XH-A(LF)(SN) | SHDR4W64P0X250_1X4_1240X575X70 | J1 | XH-2.5mm Header top entry 4 way JST XH Series, Series Number B4B, 2.5mm Pitch 4 Way 1 Row Straight PCB Header, Solder Termination, 3A | B4B-XH-A(LF)(SN) | https://www.arrow.com/en/products/b4b-xh-a-lf-sn/jst-manufacturing | XH-2.5mm Header top entry 4 way JST XH Series, Series Number B4B, 2.5mm Pitch 4 Way 1 Row Straight PCB Header, Solder Termination, 3A | 7mm | JST (JAPAN SOLDERLESS TERMINALS) | B4B-XH-A(LF)(SN) | 1724913 | http://uk.rs-online.com/web/p/products/1724913
1 | NE555D | NE555D | SO08 | IC1 | TIMER
1 | SFH_2270_R | SFH_2270_R | SFH2270R | LED2 | Osram Opto SFH 2270 R Visible Light Photodiode, SMD Top LED | SFH 2270 R | https://www.arrow.com/en/products/sfh2270r/osram-opto-semiconductors | Osram Opto SFH 2270 R Visible Light Photodiode, SMD Top LED | mm | OSRAM Opto Semiconductors | SFH 2270 R | 7080561 | http://uk.rs-online.com/web/p/products/7080561

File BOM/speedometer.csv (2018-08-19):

Qty | Value | Device | Package | Parts | Description | ALLIED_NUMBER | ALLIED_PRICE/STOCK | ARROW_PART_NUMBER | ARROW_PRICE/STOCK | DESCRIPTION | HEIGHT | MANUFACTURER_NAME | MANUFACTURER_PART_NUMBER | MF | MPN | OC_FARNELL | OC_NEWARK | RS | RS_PART_NUMBER | RS_PRICE/STOCK | SPICEPREFIX | TP_SIGNAL_NAME
1 |  | FE06-1 | FE06 | ICSP | FEMALE HEADER |  |  |  |  |  |  |  |  |  |  | unknown | unknown
1 |  | LED3MM | LED3MM | LED7 | LED
1 |  | LEDCHIPLED_1206 | CHIPLED_1206 | LED8 | LED
1 |  | LEDCHIPLED_1206 | CHIPLED_1206 | LED9 | LED |  |  |  |  |  |  |  |  |  |  |  |  |  |  |  | L
1 |  | MA05-2 | MA05-2 | SV2 | PIN HEADER |  |  |  |  |  |  |  |  |  |  | unknown | unknown
1 |  | R-US_R0805 | R0805 | R17 | RESISTOR, American symbol
1 |  | R-US_R0805 | R0805 | R24 | RESISTOR, American symbol |  |  |  |  |  |  |  |  |  |  |  |  |  |  |  | R
1 |  | SJ | SJ | SJ1 | SMD solder JUMPER
2 | 0R-JUMPA | 0R-JUMPA | A0R-JMP | JMP1, JMP3 | SMD 0R 0805 Jumper
2 | 0R-JUMPA | 0R-JUMPA | A0R-JMP | JMP2, JMP4 | SMD 0R 0805 Jumper |  |  |  |  |  |  |  |  |  |  |  |  |  |  |  | X
2 | 100 | R-US_R0805 | R0805 | R36, R37 | RESISTOR, American symbol |  |  |  |  |  |  |  |  |  |  |  |  |  | 740-8978 |  | R
7 | 100k | R-US_R0805 | R0805 | R4, R18, R22, R23, R35, R39, R42 | RESISTOR, American symbol |  |  |  |  |  |  |  |  |  |  |  |  |  |  |  | R
12 | 100n | C-EUC0603K | C0603K | C1, C2, C3, C6, C7, C8, C9, C10, C12, C22, C23, C24 | CAPACITOR, European symbol |  |  |  |  |  |  |  |  |  |  |  |  |  |  |  | C
13 | 10k | R-US_R0805 | R0805 | R1, R3, R5, R12, R13, R15, R16, R19, R20, R21, R25, R38, R41 | RESISTOR, American symbol |  |  |  |  |  |  |  |  |  |  |  |  |  |  |  | R
1 | 10n | C-EUC0805K | C0805K | C14 | CAPACITOR, European symbol |  |  |  |  |  |  |  |  |  |  |  |  |  |  |  | C
6 | 10u | C-EUC0805K | C0805K | C25, C26, C27, C28, C29, C30 | CAPACITOR, European symbol |  |  |  |  |  |  |  |  |  |  |  |  |  |  |  | C
1 | 10u | CPOL-EUA/3216-18W | A/3216-18W | C4 | POLARIZED CAPACITOR, European symbol |  |  |  |  |  |  |  |  |  |  |  |  | 501-9324 |  |  | C
1 | 18k | R-US_R0805 | R0805 | R10 | RESISTOR, American symbol |  |  |  |  |  |  |  |  |  |  |  |  |  |  |  | R
1 | 1k | R-US_R0805 | R0805 | R2 | RESISTOR, American symbol |  |  |  |  |  |  |  |  |  |  |  |  |  |  |  | R
3 | 1k5 | R-US_R0805 | R0805 | R26, R40, R43 | RESISTOR, American symbol |  |  |  |  |  |  |  |  |  |  |  |  |  |  |  | R
1 | 1n | C-EUC0805K | C0805K | C15 | CAPACITOR, European symbol |  |  |  |  |  |  |  |  |  |  |  |  |  |  |  | C
1 | 1p | C-EUC0402K | C0402K | C21 | CAPACITOR, European symbol |  |  |  |  |  |  |  |  |  |  |  |  |  |  |  | C
1 | 1p5 | C-EUC0402K | C0402K | C20 | CAPACITOR, European symbol |  |  |  |  |  |  |  |  |  |  |  |  |  |  |  | C
1 | 22k | R-US_R0805 | R0805 | R34 | RESISTOR, American symbol |  |  |  |  |  |  |  |  |  |  |  |  |  |  |  | R
1 | 24LC024SN | 24LC024SN | SO-08 | IC10 | Serial EEPROM |  |  |  |  |  |  |  |  | MICROCHIP | 24LC024/SN | 1659744 | 92C7092
1 | 2n2 | C-EUC0402K | C0402K | C18 | CAPACITOR, European symbol |  |  |  |  |  |  |  |  |  |  |  |  |  |  |  | C
1 | 2n7 | INDUCTOR | C0402K | L3
1 | 33n | C-EUC0402K | C0402K | C17 | CAPACITOR, European symbol |  |  |  |  |  |  |  |  |  |  |  |  |  |  |  | C
1 | 39k | R-US_R0805 | R0805 | R11 | RESISTOR, American symbol |  |  |  |  |  |  |  |  |  |  |  |  |  |  |  | R
1 | 3n9 | INDUCTOR | C0402K | L2
1 | 4k7 | R-US_R0805 | R0805 | R6 | RESISTOR, American symbol |  |  |  |  |  |  |  |  |  |  |  |  |  |  |  | R
1 | 4p7 | C-EUC0402K | C0402K | C19 | CAPACITOR, European symbol |  |  |  |  |  |  |  |  |  |  |  |  |  |  |  | C
1 | 4u7 | C-EUC0805K | C0805K | C5 | CAPACITOR, European symbol |  |  |  |  |  |  |  |  |  |  |  |  |  |  |  | C
2 | 4u7 | CPOL-EUSMCA | SMC_A | C11, C13 | POLARIZED CAPACITOR, European symbol |  |  |  |  |  |  |  |  |  |  |  |  |  |  |  | C
1 | 620 | R-US_R0805 | R0805 | R14 | RESISTOR, American symbol
3 | 620 | R-US_R0805 | R0805 | R7, R8, R9 | RESISTOR, American symbol |  |  |  |  |  |  |  |  |  |  |  |  |  |  |  | R
1 | 887 | R-US_R0805 | R0805 | R27 | RESISTOR, American symbol |  |  |  |  |  |  |  |  |  |  |  |  | 708-6111 |  |  | R
1 | 8n2 | INDUCTOR | C0402K | L1
1 | BAT | B2B-PH-SM4-TB(LF)(SN) | B2B-PH-SM4-TB | J2 | Wire-To-Board Connector, PH Series, 2 Contacts, Header, 2 mm, Surface Mount, 1 Rows |  |  |  |  | Wire-To-Board Connector, PH Series, 2 Contacts, Header, 2 mm, Surface Mount, 1 Rows | mm | JST (JAPAN SOLDERLESS TERMINALS) | B2B-PH-SM4-TB(LF)(SN) |  |  |  |  |  | 6881325P
1 | BAT54 | BAT54 | SOT23 | D1 | Schottky Diodes
2 | BC817 | BC817-16LT1SMD | SOT23-BEC | Q1, Q3 | NPN Transistor
2 | BC817 | BC817-16LT1SMD | SOT23-BEC | Q2, Q4 | NPN Transistor |  |  |  |  |  |  |  |  |  |  |  |  |  |  |  | Q
1 | BC817-16LT1SMD | BC817-16LT1SMD | SOT23-BEC | T1 | NPN Transistor
1 | BQ24075RGTT | BQ24075RGTT | QFN50P300X300X80-17N | IC7 | 1.5A Li-Ion Charger, Power-Path VQFN16EP BQ24075RGTT, Battery Charge Controller, Lithium-Ion, 4500mA, 16-Pin QFN |  |  | BQ24075RGTT | https://www.arrow.com/en/products/bq24075rgtt/texas-instruments | 1.5A Li-Ion Charger, Power-Path VQFN16EP BQ24075RGTT, Battery Charge Controller, Lithium-Ion, 4500mA, 16-Pin QFN | 0.8mm | Texas Instruments | BQ24075RGTT |  |  |  |  |  | 8175815P | http://uk.rs-online.com/web/p/products/8175815P
1 | Blue | LED3MM | LED3MM | LED4 | LED
1 | Blue | LEDCHIPLED_1206 | CHIPLED_1206 | LED3 | LED
1 | CONUFL001-SMD-T | CONUFL001-SMD-T | CONUFL001-SMD | J3 | RF Connectors / Coaxial Connectors T&R U.FL Straight Surface Mount Jack |  |  | CONUFL001-SMD-T |  | RF Connectors / Coaxial Connectors T&R U.FL Straight Surface Mount Jack | mm | Linx Technologies | CONUFL001-SMD-T
1 | CSTCE12M0G15L99-R0 | CSTCE12M0G15L99-R0 | CSTCE_G | IC3 | CSTCE12M0G15L99-R0, Ceramic Resonator, 12MHz Shear 33pF, 3-Pin SMT, 3.2 x 1.3 x 0.7mm |  |  | CSTCE12M0G15L99-R0 | https://www.arrow.com/en/products/cstce12m0g15l99-r0/murata-manufacturing | CSTCE12M0G15L99-R0, Ceramic Resonator, 12MHz Shear 33pF, 3-Pin SMT, 3.2 x 1.3 x 0.7mm | mm | Murata Electronics | CSTCE12M0G15L99-R0 |  |  |  |  |  | 7926527P | http://uk.rs-online.com/web/p/products/7926527P
1 | CSTCE16M0V53-R0 | CSTCE12M0G15L99-R0 | CSTCE_G | IC9 | CSTCE12M0G15L99-R0, Ceramic Resonator, 12MHz Shear 33pF, 3-Pin SMT, 3.2 x 1.3 x 0.7mm |  |  | CSTCE12M0G15L99-R0 | https://www.arrow.com/en/products/cstce12m0g15l99-r0/murata-manufacturing | CSTCE12M0G15L99-R0, Ceramic Resonator, 12MHz Shear 33pF, 3-Pin SMT, 3.2 x 1.3 x 0.7mm | mm | Murata Electronics | CSTCE12M0G15L99-R0 |  |  |  |  |  | 7926527P | http://uk.rs-online.com/web/p/products/7926527P
1 | CSTCE8M00G55-R0 | CSTCE12M0G15L99-R0 | CSTCE_G | IC2 | CSTCE12M0G15L99-R0, Ceramic Resonator, 12MHz Shear 33pF, 3-Pin SMT, 3.2 x 1.3 x 0.7mm |  |  | CSTCE12M0G15L99-R0 | https://www.arrow.com/en/products/cstce12m0g15l99-r0/murata-manufacturing | CSTCE12M0G15L99-R0, Ceramic Resonator, 12MHz Shear 33pF, 3-Pin SMT, 3.2 x 1.3 x 0.7mm | mm | Murata Electronics | CSTCE12M0G15L99-R0 |  |  |  |  |  | 7926527P | http://uk.rs-online.com/web/p/products/7926527P
1 | Green | LEDCHIPLED_1206 | CHIPLED_1206 | LED1 | LED
1 | HM-10 | HM-10 | HM-10 | U1
1 | Left | B2B-XH-A(LF)(SN) | SHDR2W64P0X250_1X2_740X575X700 | J7 | JST XH Series, 2.5mm Pitch 2 Way 1 Row Straight PCB Header, Solder Termination, 3A |  |  | B2B-XH-A(LF)(SN) | https://www.arrow.com/en/products/b2b-xh-a-lf-sn/jst-manufacturing | JST XH Series, 2.5mm Pitch 2 Way 1 Row Straight PCB Header, Solder Termination, 3A | 7mm | JST (JAPAN SOLDERLESS TERMINALS) | B2B-XH-A(LF)(SN) |  |  |  |  |  | 1667312 | http://uk.rs-online.com/web/p/products/1667312 | B
1 | Left_sens | B4B-XH-A(LF)(SN) | SHDR4W64P0X250_1X4_1240X575X70 | J6 | XH-2.5mm Header top entry 4 way JST XH Series, Series Number B4B, 2.5mm Pitch 4 Way 1 Row Straight PCB Header, Solder Termination, 3A |  |  | B4B-XH-A(LF)(SN) | https://www.arrow.com/en/products/b4b-xh-a-lf-sn/jst-manufacturing | XH-2.5mm Header top entry 4 way JST XH Series, Series Number B4B, 2.5mm Pitch 4 Way 1 Row Straight PCB Header, Solder Termination, 3A | 7mm | JST (JAPAN SOLDERLESS TERMINALS) | B4B-XH-A(LF)(SN) |  |  |  |  |  | 1724913 | http://uk.rs-online.com/web/p/products/1724913 | E
1 | MAX16054AZT+T | MAX16054AZT+T | SOT95P275X110-6N | IC11 | On Off Controller, Debounce, 15kV ESD MAX16054AZT+T, Voltage Supervisor No Push Button Controller 6-Pin SOT-23 |  |  | MAX16054AZT+T | http://uk.rs-online.com/web/p/products/9237416 | On Off Controller, Debounce, 15kV ESD MAX16054AZT+T, Voltage Supervisor No Push Button Controller 6-Pin SOT-23 | 1.1mm | Maxim Integrated | MAX16054AZT+T |  |  |  |  |  | 9237416 | http://uk.rs-online.com/web/p/products/9237416
1 | MCP2200-I_SO | MCP2200-I_SO | SOIC127P1030X265-20N | IC4 | USB 2.0 to serial UART converter w/ GPIO | 70047463 | http://www.alliedelec.com/microchip-technology-inc-mcp2200-i-so/70047463/ | MCP2200-I/SO | https://www.arrow.com/en/products/mcp2200-iso/microchip-technology | USB 2.0 to serial UART converter w/ GPIO | 2.65mm | Microchip | MCP2200-I/SO |  |  |  |  |  | 6988993P | http://uk.rs-online.com/web/p/products/6988993P
1 | NRF24L01P-T | NRF24L01P-T | QFN50P400X400X95-21N | IC8 | RF Transceiver IC 2.4GHz ISM Band QFN20 Nordic Semiconductor NRF24L01P-T, RF Transceiver 2400MHz to 2483.5MHz 1.9 3.6 V 20-Pin QFN |  |  | nRF24L01P-T | https://www.arrow.com/en/products/nrf24l01p-t/nordic-semiconductor | RF Transceiver IC 2.4GHz ISM Band QFN20 Nordic Semiconductor NRF24L01P-T, RF Transceiver 2400MHz to 2483.5MHz 1.9 3.6 V 20-Pin QFN | 0.95mm | Nordic Semiconductor | nRF24L01P-T |  |  |  |  |  | 8855748P | http://uk.rs-online.com/web/p/products/8855748P
1 | PCF8574T | PCF8574T | SO16W | IC6 | I2C-Bus Remote 8-bit I/O expander |  |  |  |  |  |  |  |  |  | PCF8574T/3,512 | 1201255 | 70R6870
1 | PIC32MX110F016B-I_SO | PIC32MX110F016B-I_SO | SOIC127P1030X265-28N | IC1 | 32-bit Microcontrollers (up to 256 KB Flash and 64 KB SRAM) with Audio and Graphics Interfaces, USB, and Advanced Analog | 70452123 | http://www.alliedelec.com/microchip-technology-inc-pic32mx110f016b-i-so/70452123/ | PIC32MX110F016B-I/SO | https://www.arrow.com/en/products/pic32mx110f016b-iso/microchip-technology | 32-bit Microcontrollers (up to 256 KB Flash and 64 KB SRAM) with Audio and Graphics Interfaces, USB, and Advanced Analog | 2.65mm | Microchip | PIC32MX110F016B-I/SO
1 | PTS645VJM61LFS | PTS645VJM61LFS | PTS645VJM61LFS | S1 | Tactile Switches Tact |  |  | PTS645VJM61LFS |  | Tactile Switches Tact | 7mm | C & K COMPONENTS | PTS645VJM61LFS
1 | Red | LED3MM | LED3MM | LED5 | LED
1 | Red | LEDCHIPLED_1206 | CHIPLED_1206 | LED2 | LED
1 | Right | B2B-XH-A(LF)(SN) | SHDR2W64P0X250_1X2_740X575X700 | J5 | JST XH Series, 2.5mm Pitch 2 Way 1 Row Straight PCB Header, Solder Termination, 3A |  |  | B2B-XH-A(LF)(SN) | https://www.arrow.com/en/products/b2b-xh-a-lf-sn/jst-manufacturing | JST XH Series, 2.5mm Pitch 2 Way 1 Row Straight PCB Header, Solder Termination, 3A | 7mm | JST (JAPAN SOLDERLESS TERMINALS) | B2B-XH-A(LF)(SN) |  |  |  |  |  | 1667312 | http://uk.rs-online.com/web/p/products/1667312
1 | Right_sens | B4B-XH-A(LF)(SN) | SHDR4W64P0X250_1X4_1240X575X70 | J4 | XH-2.5mm Header top entry 4 way JST XH Series, Series Number B4B, 2.5mm Pitch 4 Way 1 Row Straight PCB Header, Solder Termination, 3A |  |  | B4B-XH-A(LF)(SN) | https://www.arrow.com/en/products/b4b-xh-a-lf-sn/jst-manufacturing | XH-2.5mm Header top entry 4 way JST XH Series, Series Number B4B, 2.5mm Pitch 4 Way 1 Row Straight PCB Header, Solder Termination, 3A | 7mm | JST (JAPAN SOLDERLESS TERMINALS) | B4B-XH-A(LF)(SN) |  |  |  |  |  | 1724913 | http://uk.rs-online.com/web/p/products/1724913
1 | TBD | R-US_R0805 | R0805 | R28 | RESISTOR, American symbol |  |  |  |  |  |  |  |  |  |  |  |  | 708-6111 |  |  | R
1 | TPB1,27 | TPB1,27 | B1,27 | TP29 | Test pad |  |  |  |  |  |  |  |  |  |  |  |  |  |  |  |  | TP_!CHG
1 | TPB1,27 | TPB1,27 | B1,27 | TP14 | Test pad |  |  |  |  |  |  |  |  |  |  |  |  |  |  |  |  | TP_!MCLR
1 | TPB1,27 | TPB1,27 | B1,27 | TP31 | Test pad |  |  |  |  |  |  |  |  |  |  |  |  |  |  |  |  | TP_!PGOOD
1 | TPB1,27 | TPB1,27 | B1,27 | TP34 | Test pad |  |  |  |  |  |  |  |  |  |  |  |  |  |  |  |  | TP_3V3
1 | TPB1,27 | TPB1,27 | B1,27 | TP35 | Test pad |  |  |  |  |  |  |  |  |  |  |  |  |  |  |  |  | TP_5V
1 | TPB1,27 | TPB1,27 | B1,27 | TP13 | Test pad |  |  |  |  |  |  |  |  |  |  |  |  |  |  |  |  | TP_APP/BL
1 | TPB1,27 | TPB1,27 | B1,27 | TP22 | Test pad |  |  |  |  |  |  |  |  |  |  |  |  |  |  |  |  | TP_BT_KEY
1 | TPB1,27 | TPB1,27 | B1,27 | TP21 | Test pad |  |  |  |  |  |  |  |  |  |  |  |  |  |  |  |  | TP_BT_RX
1 | TPB1,27 | TPB1,27 | B1,27 | TP20 | Test pad |  |  |  |  |  |  |  |  |  |  |  |  |  |  |  |  | TP_BT_TX
1 | TPB1,27 | TPB1,27 | B1,27 | TP19 | Test pad |  |  |  |  |  |  |  |  |  |  |  |  |  |  |  |  | TP_CC_!RST
1 | TPB1,27 | TPB1,27 | B1,27 | TP18 | Test pad |  |  |  |  |  |  |  |  |  |  |  |  |  |  |  |  | TP_DBG_RX
1 | TPB1,27 | TPB1,27 | B1,27 | TP15 | Test pad |  |  |  |  |  |  |  |  |  |  |  |  |  |  |  |  | TP_DBG_TX
1 | TPB1,27 | TPB1,27 | B1,27 | TP26 | Test pad |  |  |  |  |  |  |  |  |  |  |  |  |  |  |  |  | TP_EN1
1 | TPB1,27 | TPB1,27 | B1,27 | TP27 | Test pad |  |  |  |  |  |  |  |  |  |  |  |  |  |  |  |  | TP_EN2
1 | TPB1,27 | TPB1,27 | B1,27 | TP28 | Test pad |  |  |  |  |  |  |  |  |  |  |  |  |  |  |  |  | TP_GND
1 | TPB1,27 | TPB1,27 | B1,27 | TP9 | Test pad |  |  |  |  |  |  |  |  |  |  |  |  |  |  |  |  | TP_LEFT
1 | TPB1,27 | TPB1,27 | B1,27 | TP36 | Test pad |  |  |  |  |  |  |  |  |  |  |  |  |  |  |  |  | TP_L_DX
1 | TPB1,27 | TPB1,27 | B1,27 | TP12 | Test pad |  |  |  |  |  |  |  |  |  |  |  |  |  |  |  |  | TP_MCP_RST
1 | TPB1,27 | TPB1,27 | B1,27 | TP2 | Test pad |  |  |  |  |  |  |  |  |  |  |  |  |  |  |  |  | TP_MODE
1 | TPB1,27 | TPB1,27 | B1,27 | TP1 | Test pad |  |  |  |  |  |  |  |  |  |  |  |  |  |  |  |  | TP_RIGHT
1 | TPB1,27 | TPB1,27 | B1,27 | TP3 | Test pad |  |  |  |  |  |  |  |  |  |  |  |  |  |  |  |  | TP_SCL
1 | TPB1,27 | TPB1,27 | B1,27 | TP4 | Test pad |  |  |  |  |  |  |  |  |  |  |  |  |  |  |  |  | TP_SDA
1 | TPB1,27 | TPB1,27 | B1,27 | TP33 | Test pad |  |  |  |  |  |  |  |  |  |  |  |  |  |  |  |  | TP_SYS_EN
1 | TPB1,27 | TPB1,27 | B1,27 | TP16 | Test pad |  |  |  |  |  |  |  |  |  |  |  |  |  |  |  |  | TP_USBCFG
1 | TPB1,27 | TPB1,27 | B1,27 | TP17 | Test pad |  |  |  |  |  |  |  |  |  |  |  |  |  |  |  |  | TP_USB_SSPND
1 | TPB1,27 | TPB1,27 | B1,27 | TP23 | Test pad |  |  |  |  |  |  |  |  |  |  |  |  |  |  |  |  | TP_VBAT
1 | TPB1,27 | TPB1,27 | B1,27 | TP30 | Test pad |  |  |  |  |  |  |  |  |  |  |  |  |  |  |  |  | TP_VCCINT
1 | TPB1,27 | TPB1,27 | B1,27 | TP25 | Test pad |  |  |  |  |  |  |  |  |  |  |  |  |  |  |  |  | TP_VUSB
1 | TPB1,27 | TPB1,27 | B1,27 | TP11 | Test pad |  |  |  |  |  |  |  |  |  |  |  |  |  |  |  |  | TP_nRF_CE
1 | TPB1,27 | TPB1,27 | B1,27 | TP10 | Test pad |  |  |  |  |  |  |  |  |  |  |  |  |  |  |  |  | TP_nRF_CLK
1 | TPB1,27 | TPB1,27 | B1,27 | TP8 | Test pad |  |  |  |  |  |  |  |  |  |  |  |  |  |  |  |  | TP_nRF_CS
1 | TPB1,27 | TPB1,27 | B1,27 | TP7 | Test pad |  |  |  |  |  |  |  |  |  |  |  |  |  |  |  |  | TP_nRF_IRQ
1 | TPB1,27 | TPB1,27 | B1,27 | TP6 | Test pad |  |  |  |  |  |  |  |  |  |  |  |  |  |  |  |  | TP_nRF_MISO
1 | TPB1,27 | TPB1,27 | B1,27 | TP5 | Test pad |  |  |  |  |  |  |  |  |  |  |  |  |  |  |  |  | TP_nRF_MOSI
1 | TPB1,27 | TPB1,27 | B1,27 | TP37 | Test pad |  |  |  |  |  |  |  |  |  |  |  |  |  |  |  | X | TP_L_SX
1 | TPS63001DRCT | TPS63000DRCT | SON50P300X300X100-11N | IC12 | TPS63000DRCT Buck/Boost Converter, 1.2A, Adjustable, 1.2 5.5 V, 1500 kHz, 10-Pin SON EP |  |  | TPS63000DRCT | https://www.arrow.com/en/products/tps63000drct/texas-instruments | TPS63000DRCT Buck/Boost Converter, 1.2A, Adjustable, 1.2 5.5 V, 1500 kHz, 10-Pin SON EP | 1mm | Texas Instruments | TPS63000DRCT |  |  |  |  |  | 0389334P | http://uk.rs-online.com/web/p/products/0389334P
1 | TPS63002DRCT | TPS63000DRCT | SON50P300X300X100-11N | IC13 | TPS63000DRCT Buck/Boost Converter, 1.2A, Adjustable, 1.2 5.5 V, 1500 kHz, 10-Pin SON EP |  |  | TPS63000DRCT | https://www.arrow.com/en/products/tps63000drct/texas-instruments | TPS63000DRCT Buck/Boost Converter, 1.2A, Adjustable, 1.2 5.5 V, 1500 kHz, 10-Pin SON EP | 1mm | Texas Instruments | TPS63000DRCT |  |  |  |  |  | 0389334P | http://uk.rs-online.com/web/p/products/0389334P
2 | VLF4012AT-2R2M1R5 | VLF4012AT-3R3M1R3 | VLF4012A | L4, L5 | Fixed Inductors 3.3uH 1.3A 4x4x1.2mm |  |  | VLF4012AT-3R3M1R3 | https://www.arrow.com/en/products/vlf4012at-3r3m1r3/tdk | Fixed Inductors 3.3uH 1.3A 4x4x1.2mm | mm | TDK | VLF4012AT-3R3M1R3 |  |  |  |  |  | 644-1952
1 | microUSB | 10104111-0001LF | MICRO_USB_A/B_TYPE_RECEPTACLE | J1 | FCI Right Angle SMT Female Type AB Version 2.0 Micro USB Connector, 100 V ac, 1.8A | 70236825 |  |  |  | FCI Right Angle SMT Female Type AB Version 2.0 Micro USB Connector, 100 V ac, 1.8A | mm | FCI | 10104111-0001LF |  |  |  |  |  | 1622014

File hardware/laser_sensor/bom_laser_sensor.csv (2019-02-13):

Part | Value | Device | Package | Description | ARROW_PART_NUMBER | ARROW_PRICE/STOCK | DESCRIPTION | HEIGHT | MANUFACTURER_NAME | MANUFACTURER_PART_NUMBER | MOUSER_PART_NUMBER | MOUSER_PRICE-STOCK | RS_PART_NUMBER | RS_PRICE-STOCK | RS_PRICE/STOCK | SPICEPREFIX
D1 | SFH_2440_L | SFH_2440_L | SFH2440L | Silicon Photodiode, Human Eye Sensitive |  |  | Silicon Photodiode, Human Eye Sensitive | mm | OSRAM Opto Semiconductors | SFH 2440 L | 720-SFH2440L | https://www.mouser.com/Search/Refine.aspx?Keyword=720-SFH2440L | 1243361P | http://uk.rs-online.com/web/p/products/1243361P
J1 | B4B-XH-A(LF)(SN) | B4B-XH-A(LF)(SN) | SHDR4W64P0X250_1X4_1240X575X70 | XH-2.5mm Header top entry 4 way JST XH Series, Series Number B4B, 2.5mm Pitch 4 Way 1 Row Straight PCB Header, Solder Termination, 3A | B4B-XH-A(LF)(SN) | https://www.arrow.com/en/products/b4b-xh-a-lf-sn/jst-manufacturing | XH-2.5mm Header top entry 4 way JST XH Series, Series Number B4B, 2.5mm Pitch 4 Way 1 Row Straight PCB Header, Solder Termination, 3A | 7mm | JST (JAPAN SOLDERLESS TERMINALS) | B4B-XH-A(LF)(SN) |  |  | 1724913 |  | http://uk.rs-online.com/web/p/products/1724913
LED1 |  | LED3MM | LED3MM | LED
Q1 | BC817-16LT1SMD | BC817-16LT1SMD | SOT23-BEC | NPN Transistor
R1 | 100k | R-US_R0603 | R0603 | RESISTOR, American symbol |  |  |  |  |  |  |  |  |  |  |  | R
R2 | 100k | R-US_R0603 | R0603 | RESISTOR, American symbol |  |  |  |  |  |  |  |  |  |  |  | R
R3 | 10k | R-US_R0603 | R0603 | RESISTOR, American symbol |  |  |  |  |  |  |  |  |  |  |  | R
R4 | 560 | R-US_R0603 | R0603 | RESISTOR, American symbol |  |  |  |  |  |  |  |  |  |  |  | R

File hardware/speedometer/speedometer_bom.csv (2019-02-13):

Part | Value | Device | Package | Description | ALLIED_NUMBER | ARROW_PART_NUMBER | ARROW_PRICE-STOCK | ARROW_PRICE/STOCK | DESCRIPTION | HEIGHT | MANUFACTURER_NAME | MANUFACTURER_PART_NUMBER | MF | MPN | OC_FARNELL | OC_NEWARK | RS | RS_PART_NUMBER | RS_PRICE-STOCK | RS_PRICE/STOCK | SPICEPREFIX | TP_SIGNAL_NAME
ANT1 | M310210 | M310210 | M310210
C1 | 100n | C-EUC0603K | C0603K | CAPACITOR, European symbol |  |  |  |  |  |  |  |  |  |  |  |  |  |  |  |  | C
C2 | 100n | C-EUC0603K | C0603K | CAPACITOR, European symbol |  |  |  |  |  |  |  |  |  |  |  |  |  |  |  |  | C
C3 | 10u | C-EUC0805K | C0805K | CAPACITOR, European symbol |  |  |  |  |  |  |  |  |  |  |  |  |  |  |  |  | C
C4 | 100n | C-EUC0603K | C0603K | CAPACITOR, European symbol |  |  |  |  |  |  |  |  |  |  |  |  |  |  |  |  | C
C5 | 100n | C-EUC0603K | C0603K | CAPACITOR, European symbol |  |  |  |  |  |  |  |  |  |  |  |  |  |  |  |  | C
C6 | 100n | C-EUC0603K | C0603K | CAPACITOR, European symbol |  |  |  |  |  |  |  |  |  |  |  |  |  |  |  |  | C
C7 | 100n | C-EUC0603K | C0603K | CAPACITOR, European symbol |  |  |  |  |  |  |  |  |  |  |  |  |  |  |  |  | C
C8 | 1u | C-EUC0603K | C0603K | CAPACITOR, European symbol |  |  |  |  |  |  |  |  |  |  |  |  |  |  |  |  | C
C9 | 470n | C-EUC0603K | C0603K | CAPACITOR, European symbol |  |  |  |  |  |  |  |  |  |  |  |  |  |  |  |  | C
C10 | 10u | C-EUC0805K | C0805K | CAPACITOR, European symbol |  |  |  |  |  |  |  |  |  |  |  |  |  |  |  |  | C
C11 | 10u | C-EUC0805K | C0805K | CAPACITOR, European symbol |  |  |  |  |  |  |  |  |  |  |  |  |  |  |  |  | C
C12 | 10u | C-EUC0805K | C0805K | CAPACITOR, European symbol |  |  |  |  |  |  |  |  |  |  |  |  |  |  |  |  | C
C13 | 10n | C-EUC0603K | C0603K | CAPACITOR, European symbol |  |  |  |  |  |  |  |  |  |  |  |  |  |  |  |  | C
C14 | 1n | C-EUC0603K | C0603K | CAPACITOR, European symbol |  |  |  |  |  |  |  |  |  |  |  |  |  |  |  |  | C
C15 | 1n | C-EUC0603K | C0603K | CAPACITOR, European symbol |  |  |  |  |  |  |  |  |  |  |  |  |  |  |  |  | C
C16 | 33n | C-EUC0402K | C0402K | CAPACITOR, European symbol |  |  |  |  |  |  |  |  |  |  |  |  |  |  |  |  | C
C17 | 2n2 | C-EUC0402K | C0402K | CAPACITOR, European symbol |  |  |  |  |  |  |  |  |  |  |  |  |  |  |  |  | C
C18 |  | C-EUC0402K | C0402K | CAPACITOR, European symbol |  |  |  |  |  |  |  |  |  |  |  |  |  |  |  |  | C
C19 | 4p7 | C-EUC0402K | C0402K | CAPACITOR, European symbol |  |  |  |  |  |  |  |  |  |  |  |  |  |  |  |  | C
C20 | 1p | C-EUC0402K | C0402K | CAPACITOR, European symbol |  |  |  |  |  |  |  |  |  |  |  |  |  |  |  |  | C
C21 |  | C-EUC0402K | C0402K | CAPACITOR, European symbol |  |  |  |  |  |  |  |  |  |  |  |  |  |  |  |  | C
C22 |  | C-EUC0402K | C0402K | CAPACITOR, European symbol |  |  |  |  |  |  |  |  |  |  |  |  |  |  |  |  | C
C23 |  | C-EUC0402K | C0402K | CAPACITOR, European symbol |  |  |  |  |  |  |  |  |  |  |  |  |  |  |  |  | C
C24 | 100n | C-EUC0603K | C0603K | CAPACITOR, European symbol |  |  |  |  |  |  |  |  |  |  |  |  |  |  |  |  | C
C25 | 10u | C-EUC0805K | C0805K | CAPACITOR, European symbol |  |  |  |  |  |  |  |  |  |  |  |  |  |  |  |  | C
C26 | 10u | C-EUC0805K | C0805K | CAPACITOR, European symbol |  |  |  |  |  |  |  |  |  |  |  |  |  |  |  |  | C
C27 | 100n | C-EUC0603K | C0603K | CAPACITOR, European symbol |  |  |  |  |  |  |  |  |  |  |  |  |  |  |  |  | C
C28 | 100n | C-EUC0603K | C0603K | CAPACITOR, European symbol |  |  |  |  |  |  |  |  |  |  |  |  |  |  |  |  | C
C29 | 10u | C-EUC0805K | C0805K | CAPACITOR, European symbol |  |  |  |  |  |  |  |  |  |  |  |  |  |  |  |  | C
C30 | 10u | C-EUC0805K | C0805K | CAPACITOR, European symbol |  |  |  |  |  |  |  |  |  |  |  |  |  |  |  |  | C
C31 | 10u | C-EUC0805K | C0805K | CAPACITOR, European symbol |  |  |  |  |  |  |  |  |  |  |  |  |  |  |  |  | C
C32 | 10u | C-EUC0805K | C0805K | CAPACITOR, European symbol |  |  |  |  |  |  |  |  |  |  |  |  |  |  |  |  | C
IC1 | PIC32MX274F256DT-I_PT | PIC32MX274F256DT-I_PT | QFP80P1200X1200X120-44N | 32-bit Microcontrollers - MCU 256KB Flash, 64KB RAM, 10-Bit ADC, UART, SPI/I2S, I2C + VBATT Pin, USB |  | PIC32MX274F256DT-I/PT |  |  | 32-bit Microcontrollers - MCU 256KB Flash, 64KB RAM, 10-Bit ADC, UART, SPI/I2S, I2C + VBATT Pin, USB | 1.2mm | Microchip | PIC32MX274F256DT-I/PT
IC2 | SN65220DBVRG4 | SN65220DBVRG4 | SOT95P280X145-6N | ESD Suppressors / TVS Diodes Sngl Port Transient Suppressor |  | SN65220DBVRG4 |  | https://www.arrow.com/en/products/sn65220dbvrg4/texas-instruments | ESD Suppressors / TVS Diodes Sngl Port Transient Suppressor | 1.45mm | Texas Instruments | SN65220DBVRG4
IC3 | CSTCE8M00G55-R0 | CSTCE12M0G15L99-R0 | CSTCE_G | CSTCE12M0G15L99-R0, Ceramic Resonator, 12MHz Shear 33pF, 3-Pin SMT, 3.2 x 1.3 x 0.7mm |  | CSTCE12M0G15L99-R0 |  | https://www.arrow.com/en/products/cstce12m0g15l99-r0/murata-manufacturing | CSTCE12M0G15L99-R0, Ceramic Resonator, 12MHz Shear 33pF, 3-Pin SMT, 3.2 x 1.3 x 0.7mm | mm | Murata Electronics | CSTCE12M0G15L99-R0 |  |  |  |  |  | 7926527P |  | http://uk.rs-online.com/web/p/products/7926527P
IC4 | HM-11 | HM-11 | HM-11 | JNHuaMao HM-11 Bluetooth 4.0 Transceiver
IC5 | BQ27441DRZR-G1A | BQ27441DRZR-G1A | BQ27441DRZRG1A | System-Side Impedance Track Battery Fuel (Gas) Gauge |  | BQ27441DRZR-G1A | https://www.arrow.com/en/products/bq27441drzr-g1a/texas-instruments |  | System-Side Impedance Track Battery Fuel (Gas) Gauge | mm | Texas Instruments | BQ27441DRZR-G1A
IC6 | BQ24075RGTT | BQ24075RGTT | QFN50P300X300X80-17N | 1.5A Li-Ion Charger, Power-Path VQFN16EP BQ24075RGTT, Battery Charge Controller, Lithium-Ion, 4500mA, 16-Pin QFN |  | BQ24075RGTT |  | https://www.arrow.com/en/products/bq24075rgtt/texas-instruments | 1.5A Li-Ion Charger, Power-Path VQFN16EP BQ24075RGTT, Battery Charge Controller, Lithium-Ion, 4500mA, 16-Pin QFN | 0.8mm | Texas Instruments | BQ24075RGTT |  |  |  |  |  | 8175815P |  | http://uk.rs-online.com/web/p/products/8175815P
IC7 | NRF24L01P-T | NRF24L01P-T | QFN50P400X400X95-21N | RF Transceiver IC 2.4GHz ISM Band QFN20 Nordic Semiconductor NRF24L01P-T, RF Transceiver 2400MHz to 2483.5MHz 1.9 3.6 V 20-Pin QFN |  | nRF24L01P-T |  | https://www.arrow.com/en/products/nrf24l01p-t/nordic-semiconductor | RF Transceiver IC 2.4GHz ISM Band QFN20 Nordic Semiconductor NRF24L01P-T, RF Transceiver 2400MHz to 2483.5MHz 1.9 3.6 V 20-Pin QFN | 0.95mm | Nordic Semiconductor | nRF24L01P-T |  |  |  |  |  | 8855748P |  | http://uk.rs-online.com/web/p/products/8855748P
IC8 | CSTCE16M0V53-R0 | CSTCE12M0G15L99-R0 | CSTCE_G | CSTCE12M0G15L99-R0, Ceramic Resonator, 12MHz Shear 33pF, 3-Pin SMT, 3.2 x 1.3 x 0.7mm |  | CSTCE12M0G15L99-R0 |  | https://www.arrow.com/en/products/cstce12m0g15l99-r0/murata-manufacturing | CSTCE12M0G15L99-R0, Ceramic Resonator, 12MHz Shear 33pF, 3-Pin SMT, 3.2 x 1.3 x 0.7mm | mm | Murata Electronics | CSTCE12M0G15L99-R0 |  |  |  |  |  | 7926527P |  | http://uk.rs-online.com/web/p/products/7926527P
IC9 | 24LC024ST | 24LC024ST | TSSOP8 | Serial EEPROM |  |  |  |  |  |  |  |  |  | 24LC024H-I/ST | 1659745 | 77M3584
IC10 | MAX16054AZT+T | MAX16054AZT+T | SOT95P275X110-6N | On Off Controller, Debounce, 15kV ESD MAX16054AZT+T, Voltage Supervisor No Push Button Controller 6-Pin SOT-23 |  | MAX16054AZT+T |  | http://uk.rs-online.com/web/p/products/9237416 | On Off Controller, Debounce, 15kV ESD MAX16054AZT+T, Voltage Supervisor No Push Button Controller 6-Pin SOT-23 | 1.1mm | Maxim Integrated | MAX16054AZT+T |  |  |  |  |  | 9237416 |  | http://uk.rs-online.com/web/p/products/9237416
IC11 | TPS63001DRCT | TPS63000DRCT | SON50P300X300X100-11N | TPS63000DRCT Buck/Boost Converter, 1.2A, Adjustable, 1.2 5.5 V, 1500 kHz, 10-Pin SON EP |  | TPS63000DRCT |  | https://www.arrow.com/en/products/tps63000drct/texas-instruments | TPS63000DRCT Buck/Boost Converter, 1.2A, Adjustable, 1.2 5.5 V, 1500 kHz, 10-Pin SON EP | 1mm | Texas Instruments | TPS63000DRCT |  |  |  |  |  | 0389334P |  | http://uk.rs-online.com/web/p/products/0389334P
IC12 | TPS63002DRCT | TPS63000DRCT | SON50P300X300X100-11N | TPS63000DRCT Buck/Boost Converter, 1.2A, Adjustable, 1.2 5.5 V, 1500 kHz, 10-Pin SON EP |  | TPS63000DRCT |  | https://www.arrow.com/en/products/tps63000drct/texas-instruments | TPS63000DRCT Buck/Boost Converter, 1.2A, Adjustable, 1.2 5.5 V, 1500 kHz, 10-Pin SON EP | 1mm | Texas Instruments | TPS63000DRCT |  |  |  |  |  | 0389334P |  | http://uk.rs-online.com/web/p/products/0389334P
IC13 | 74LVC1G32SE-7 | 74LVC1G32SE-7 | SOT353
J1 | 10104111-0001LF | 10104111-0001LF | MICRO_USB_A/B_TYPE_RECEPTACLE | FCI Right Angle SMT Female Type AB Version 2.0 Micro USB Connector, 100 V ac, 1.8A | 70236825 |  |  |  | FCI Right Angle SMT Female Type AB Version 2.0 Micro USB Connector, 100 V ac, 1.8A | mm | FCI | 10104111-0001LF |  |  |  |  |  | 1622014
J2 | BAT | B2B-PH-SM4-TB(LF)(SN) | B2B-PH-SM4-TB | Wire-To-Board Connector, PH Series, 2 Contacts, Header, 2 mm, Surface Mount, 1 Rows |  |  |  |  | Wire-To-Board Connector, PH Series, 2 Contacts, Header, 2 mm, Surface Mount, 1 Rows | mm | JST (JAPAN SOLDERLESS TERMINALS) | B2B-PH-SM4-TB(LF)(SN) |  |  |  |  |  | 6881325P
J3 | CONUFL001-SMD-T | CONUFL001-SMD-T | CONUFL001-SMD | RF Connectors / Coaxial Connectors T&R U.FL Straight Surface Mount Jack |  | CONUFL001-SMD-T |  |  | RF Connectors / Coaxial Connectors T&R U.FL Straight Surface Mount Jack | mm | Linx Technologies | CONUFL001-SMD-T
J4 | Right_sens | B4B-XH-A(LF)(SN) | SHDR4W64P0X250_1X4_1240X575X70 | XH-2.5mm Header top entry 4 way JST XH Series, Series Number B4B, 2.5mm Pitch 4 Way 1 Row Straight PCB Header, Solder Termination, 3A |  | B4B-XH-A(LF)(SN) |  | https://www.arrow.com/en/products/b4b-xh-a-lf-sn/jst-manufacturing | XH-2.5mm Header top entry 4 way JST XH Series, Series Number B4B, 2.5mm Pitch 4 Way 1 Row Straight PCB Header, Solder Termination, 3A | 7mm | JST (JAPAN SOLDERLESS TERMINALS) | B4B-XH-A(LF)(SN) |  |  |  |  |  | 1724913 |  | http://uk.rs-online.com/web/p/products/1724913
J5 | Right | B2B-XH-A(LF)(SN) | SHDR2W64P0X250_1X2_740X575X700 | JST XH Series, 2.5mm Pitch 2 Way 1 Row Straight PCB Header, Solder Termination, 3A |  | B2B-XH-A(LF)(SN) |  | https://www.arrow.com/en/products/b2b-xh-a-lf-sn/jst-manufacturing | JST XH Series, 2.5mm Pitch 2 Way 1 Row Straight PCB Header, Solder Termination, 3A | 7mm | JST (JAPAN SOLDERLESS TERMINALS) | B2B-XH-A(LF)(SN) |  |  |  |  |  | 1667312 |  | http://uk.rs-online.com/web/p/products/1667312
J6 | Left_sens | B4B-XH-A(LF)(SN) | SHDR4W64P0X250_1X4_1240X575X70 | XH-2.5mm Header top entry 4 way JST XH Series, Series Number B4B, 2.5mm Pitch 4 Way 1 Row Straight PCB Header, Solder Termination, 3A |  | B4B-XH-A(LF)(SN) |  | https://www.arrow.com/en/products/b4b-xh-a-lf-sn/jst-manufacturing | XH-2.5mm Header top entry 4 way JST XH Series, Series Number B4B, 2.5mm Pitch 4 Way 1 Row Straight PCB Header, Solder Termination, 3A | 7mm | JST (JAPAN SOLDERLESS TERMINALS) | B4B-XH-A(LF)(SN) |  |  |  |  |  | 1724913 |  | http://uk.rs-online.com/web/p/products/1724913 | E
J7 | Left | B2B-XH-A(LF)(SN) | SHDR2W64P0X250_1X2_740X575X700 | JST XH Series, 2.5mm Pitch 2 Way 1 Row Straight PCB Header, Solder Termination, 3A |  | B2B-XH-A(LF)(SN) |  | https://www.arrow.com/en/products/b2b-xh-a-lf-sn/jst-manufacturing | JST XH Series, 2.5mm Pitch 2 Way 1 Row Straight PCB Header, Solder Termination, 3A | 7mm | JST (JAPAN SOLDERLESS TERMINALS) | B2B-XH-A(LF)(SN) |  |  |  |  |  | 1667312 |  | http://uk.rs-online.com/web/p/products/1667312
JP1 |  | PINHD-1X3 | 1X03 | PIN HEADER
L1 | 8n2 | INDUCTOR | C0402K
L2 | 2n7 | INDUCTOR | C0402K
L3 | 3n9 | INDUCTOR | C0402K
L4 | VLF4012AT-2R2M1R5 | LPS3015-222MRB | LPS3015 | COILCRAFT - LPS3015-222MRB - INDUCTOR, SHLD, 2.2UH, 20%, 1.1A, SMD |  | LPS3015-222MRB |  |  | COILCRAFT - LPS3015-222MRB - INDUCTOR, SHLD, 2.2UH, 20%, 1.1A, SMD | mm | COILCRAFT | LPS3015-222MRB |  |  |  |  |  | 644-1952
L5 | VLF4012AT-2R2M1R5 | LPS3015-222MRB | LPS3015 | COILCRAFT - LPS3015-222MRB - INDUCTOR, SHLD, 2.2UH, 20%, 1.1A, SMD |  | LPS3015-222MRB |  |  | COILCRAFT - LPS3015-222MRB - INDUCTOR, SHLD, 2.2UH, 20%, 1.1A, SMD | mm | COILCRAFT | LPS3015-222MRB |  |  |  |  |  | 644-1952
LED1 |  | LED3MM | LED3MM | LED
LED2 |  | LEDCHIPLED_0805 | CHIPLED_0805 | LED
LED3 |  | LED3MM | LED3MM | LED
LED4 |  | LED3MM | LED3MM | LED
LED5 |  | LEDCHIPLED_1206 | CHIPLED_1206 | LED
LED6 |  | LEDCHIPLED_1206 | CHIPLED_1206 | LED
Q1 | BC817 | BC817-16LT1SMD | SOT23-BEC | NPN Transistor
Q2 | BC817 | BC817-16LT1SMD | SOT23-BEC | NPN Transistor
Q3 | BC817 | BC817-16LT1SMD | SOT23-BEC | NPN Transistor
Q4 | BC817 | BC817-16LT1SMD | SOT23-BEC | NPN Transistor |  |  |  |  |  |  |  |  |  |  |  |  |  |  |  |  | Q
R1 | 1k5 | R-US_R0603 | R0603 | RESISTOR, American symbol |  |  |  |  |  |  |  |  |  |  |  |  |  |  |  |  | R
R2 | 1k5 | R-US_R0603 | R0603 | RESISTOR, American symbol |  |  |  |  |  |  |  |  |  |  |  |  |  |  |  |  | R
R3 | 1k | R-US_R0603 | R0603 | RESISTOR, American symbol |  |  |  |  |  |  |  |  |  |  |  |  |  |  |  |  | R
R4 | 10k | R-US_R0603 | R0603 | RESISTOR, American symbol |  |  |  |  |  |  |  |  |  |  |  |  |  |  |  |  | R
R5 | 10k | R-US_R0603 | R0603 | RESISTOR, American symbol |  |  |  |  |  |  |  |  |  |  |  |  |  |  |  |  | R
R6 | 4k7 | R-US_R0603 | R0603 | RESISTOR, American symbol |  |  |  |  |  |  |  |  |  |  |  |  |  |  |  |  | R
R7 | 4k7 | R-US_R0603 | R0603 | RESISTOR, American symbol |  |  |  |  |  |  |  |  |  |  |  |  |  |  |  |  | R
R8 | 4k7 | R-US_R0603 | R0603 | RESISTOR, American symbol |  |  |  |  |  |  |  |  |  |  |  |  |  |  |  |  | R
R9 | 470 | R-US_R0603 | R0603 | RESISTOR, American symbol |  |  |  |  |  |  |  |  |  |  |  |  |  |  |  |  | R
R10 | 470 | R-US_R0603 | R0603 | RESISTOR, American symbol |  |  |  |  |  |  |  |  |  |  |  |  |  |  |  |  | R
R11 | 10m | R-US_R2512 | R2512 | RESISTOR, American symbol |  |  |  |  |  |  |  |  |  |  |  |  | 693-4381 |  |  |  | R
R12 | 10k | R-US_R0603 | R0603 | RESISTOR, American symbol |  |  |  |  |  |  |  |  |  |  |  |  |  |  |  |  | R
R13 | 10k | R-US_R0603 | R0603 | RESISTOR, American symbol |  |  |  |  |  |  |  |  |  |  |  |  |  |  |  |  | R
R14 | 10k | R-US_R0603 | R0603 | RESISTOR, American symbol |  |  |  |  |  |  |  |  |  |  |  |  |  |  |  |  | R
R15 | 100k | R-US_R0603 | R0603 | RESISTOR, American symbol |  |  |  |  |  |  |  |  |  |  |  |  |  |  |  |  | R
R16 | 1k5 | R-US_R0603 | R0603 | RESISTOR, American symbol |  |  |  |  |  |  |  |  |  |  |  |  |  |  |  |  | R
R17 |  | R-US_R0603 | R0603 | RESISTOR, American symbol |  |  |  |  |  |  |  |  |  |  |  |  |  |  |  |  | R
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

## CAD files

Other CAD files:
3Dparts/mirror_support .f3d
3Dparts/sensor_laser_support.f3d

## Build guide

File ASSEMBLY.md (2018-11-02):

# Assembly

Since there are three different voltage domains is important to check that the different voltages are provided correctly. Keep this list while assembling the board. Go ahead only if the previous step ended successfully.

Step|Aim|Components|Expected Result
--|--|--|--
1|The USB provide 5V|J1|Around 5V between TP25 (+) and TP28(-).
2|The battery polarity is correct|J2| 3.4 < V < 4.2 between  TP23(+) and TP28(-).
3|The charger works|IC7, C11, C12, C13, R19, R22, R24, R26, R27, R28|LED7 lights up. TP31 is low. Between TP30 and TP28 we have a voltage between 3.4V and 5.5V. **Note 1**.
4|The power button latch works|S1, IC11|After pressing S1, TP33 goes high. Pressing S1 again and TP33 return to ground.
5|The 3V3 switching circuit works|IC12, R36, C23, C25, C27, C29, L4|TP34 is in HiZ. After pressing S1 between TP34 and TP28 there are 3V3. Repeat with USB + Battery and Battery only.
6|The 5V switching circuit works|IC13, R37, C24, C26, C28, C30|TP35 is in HiZ. After pressing S1 between TP35 and TP28 there are 5V. Repeat with USB + Battery and Battery only.

If all the 6 steps are passed it's possible to mount the other components and proceed with the communication tests. See **TODO** for more information.

As recap, with USB and/or battery connected we should have the following voltages (the ground  reference is **TP28**):

Test Point|Voltage|Source
--|--|--
TP25|~5V|USB port (J1)
TP23|3.4 < V < 4.2|Battery (J2)
TP31|TP23 < V < TP25|BQ74025 (IC7)
TP34|3V3|TPS63001 (IC12)
TP35|5V|TPS63002 (IC13)

Be sure to power on the board by pressing **S1**.

# Notes
1. The battery charger gots 2 input pins to select the max current used to charge the battery. Since them are driven by the CPU, short **TP26** and **TP27** to **TP28** to set the charging current to **100mA**. Keep the jumpers until we solder the CPU.

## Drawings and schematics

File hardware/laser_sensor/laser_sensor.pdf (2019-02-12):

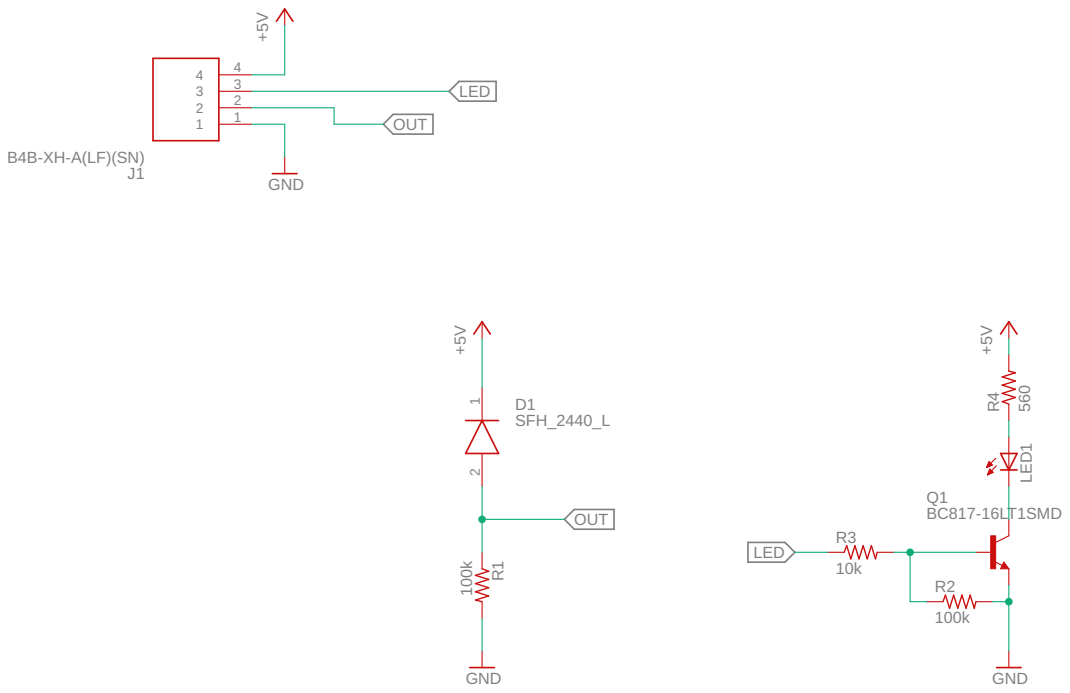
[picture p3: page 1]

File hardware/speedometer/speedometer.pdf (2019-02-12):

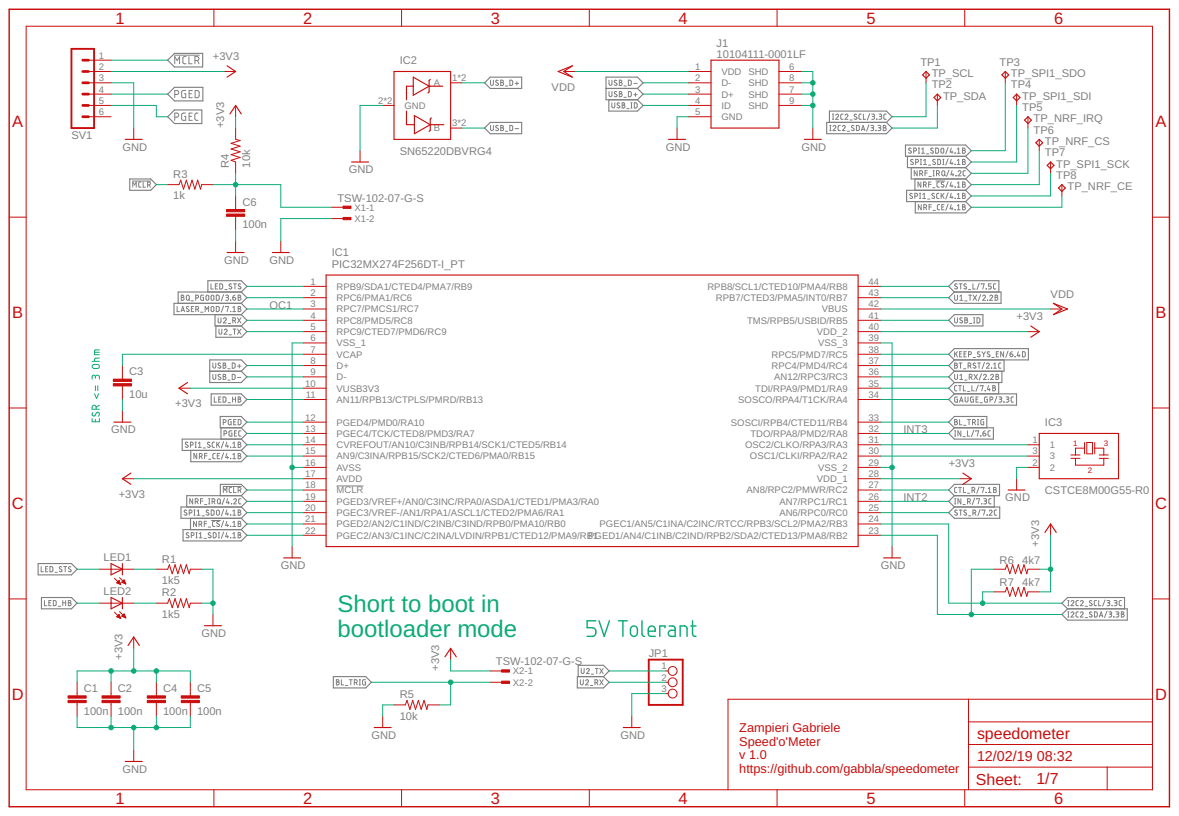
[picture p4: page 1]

3 Short to boot in

30 VSS_2 | 3
29 VDD_1 | 2 +3V3

24 PGED1/AN4/C1INB/C2IND/RPB2/SDA2/CTED13/PMA8/RB2

Zampieri Gabriele Speed'o'Meter v 1.0 https://github.com/gabbla/speedometer

Sheet: 1/7

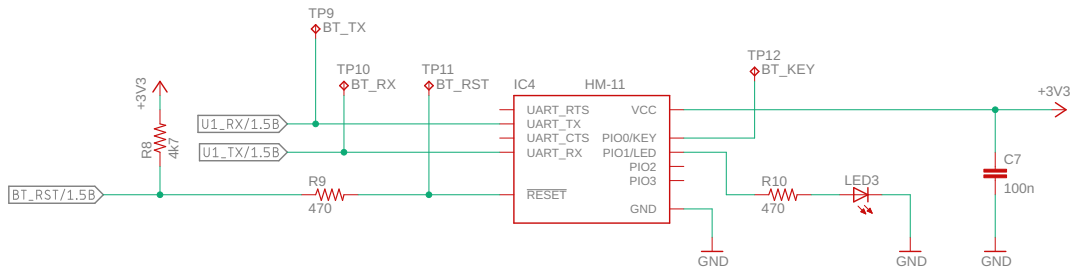
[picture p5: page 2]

Zampieri Gabriele Speed'o'Meter v 1.0 https://github.com/gabbla/speedometer

Sheet: 2/7

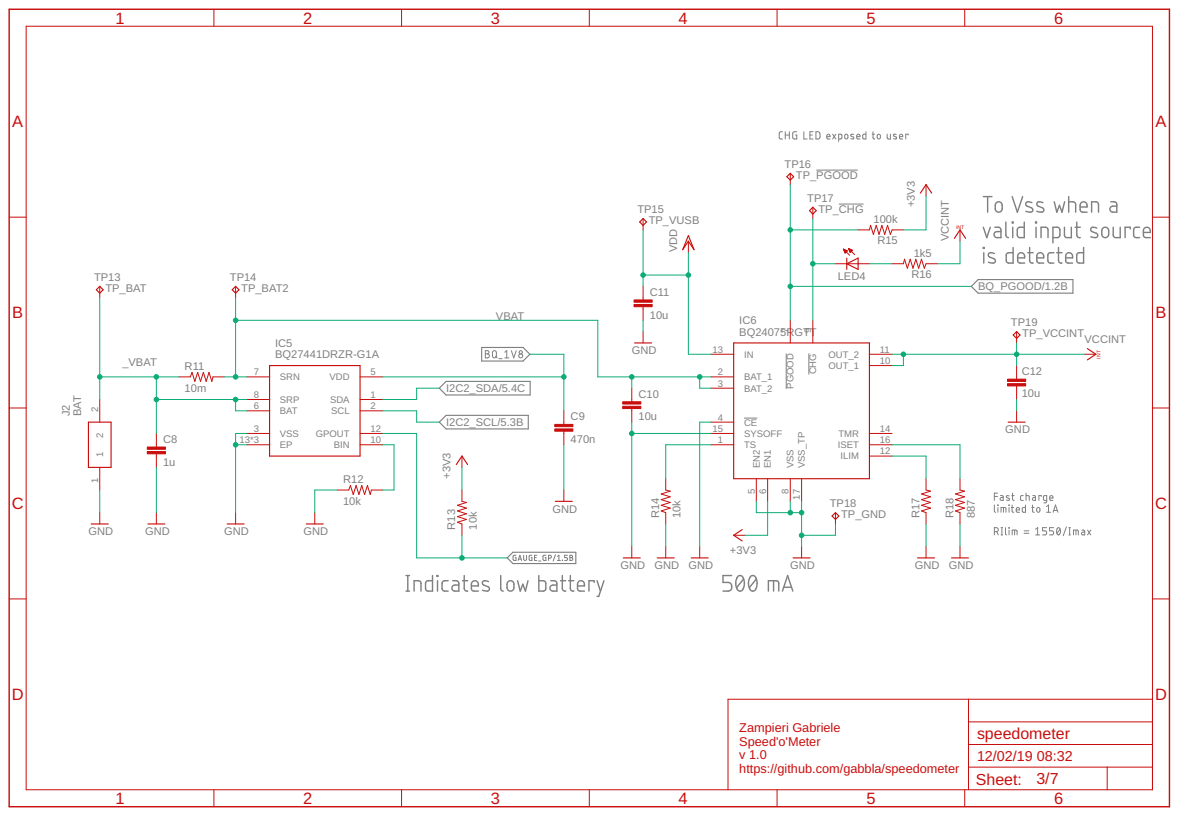
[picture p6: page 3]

Zampieri Gabriele Speed'o'Meter v 1.0 https://github.com/gabbla/speedometer

Sheet: 3/7

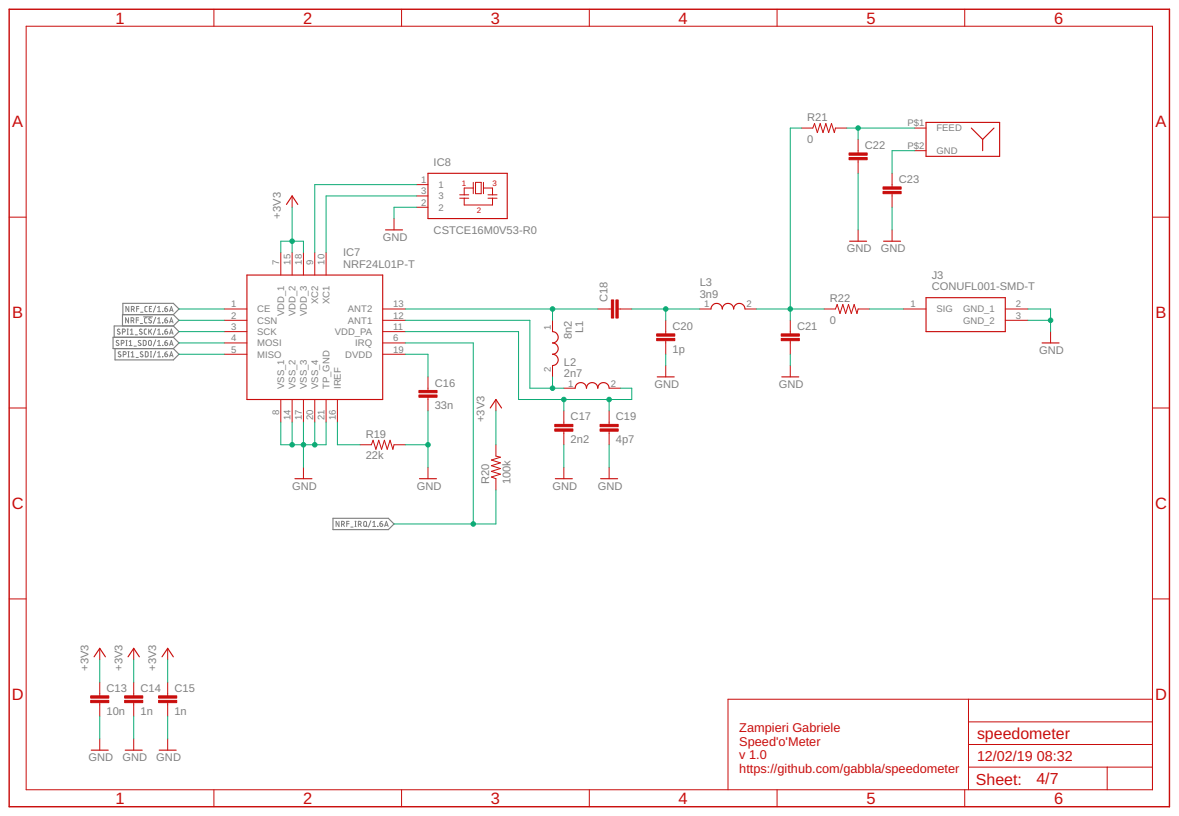
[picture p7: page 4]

Zampieri Gabriele Speed'o'Meter v 1.0 https://github.com/gabbla/speedometer

Sheet: 4/7

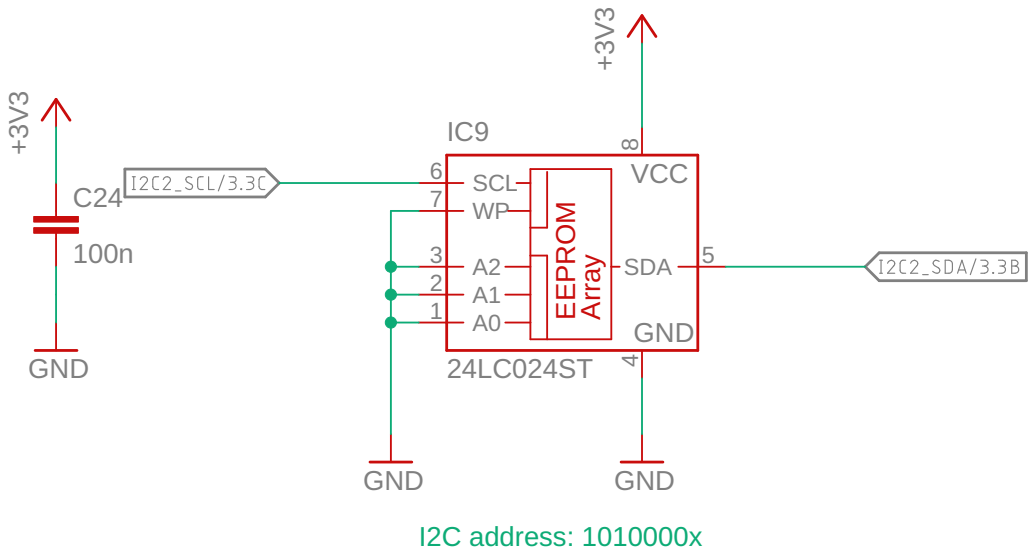
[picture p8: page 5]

Zampieri Gabriele Speed'o'Meter v 1.0 https://github.com/gabbla/speedometer

Sheet: 5/7

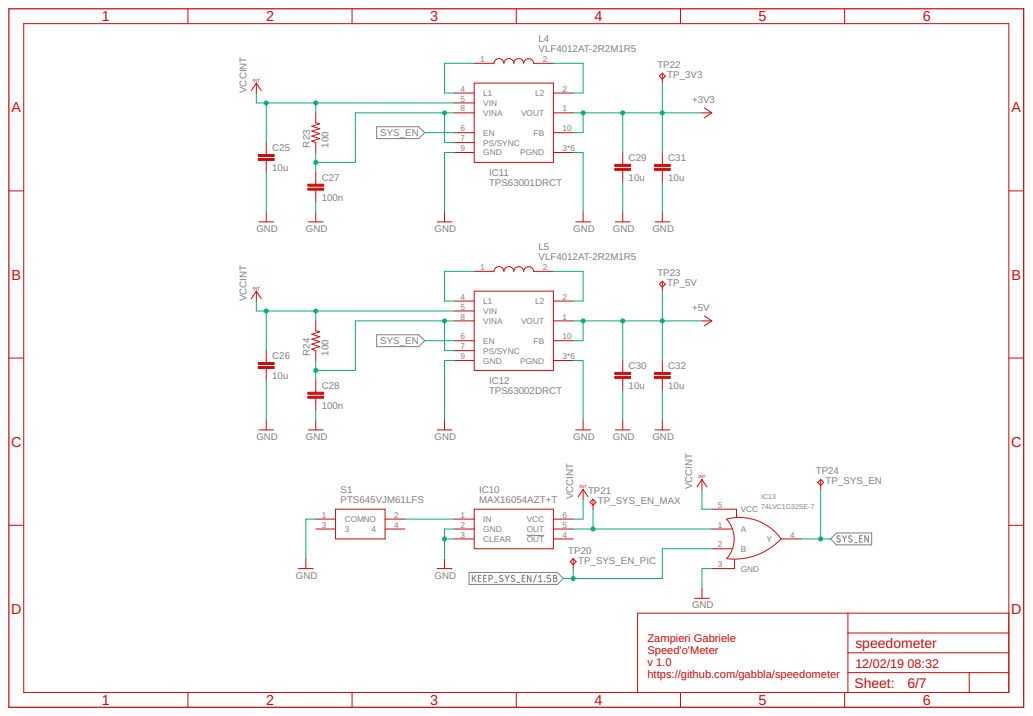
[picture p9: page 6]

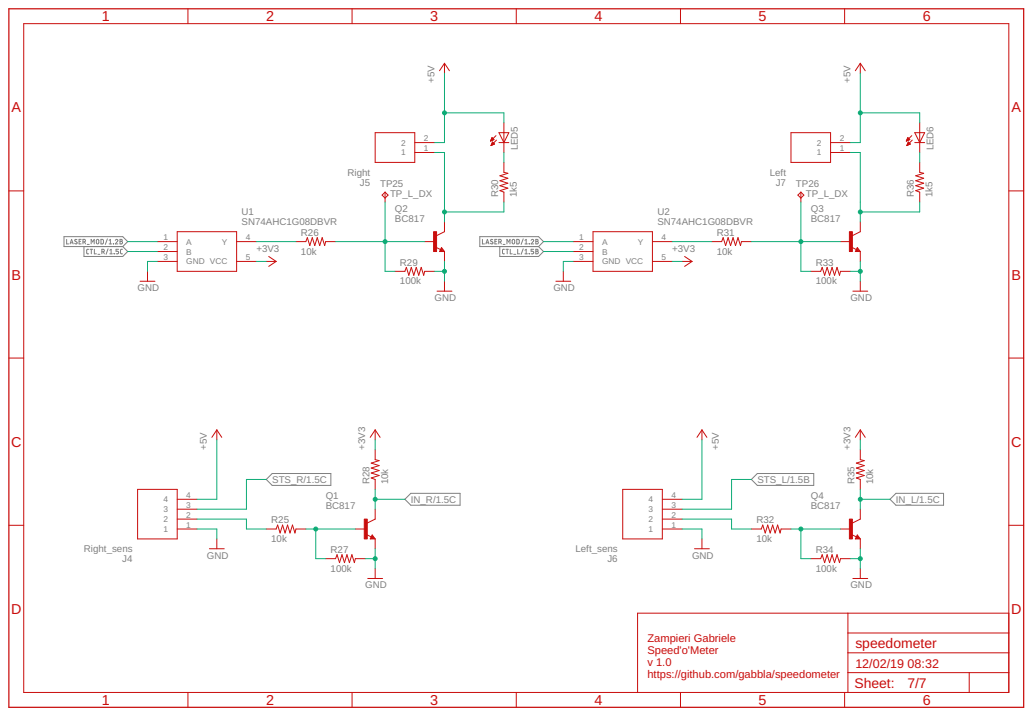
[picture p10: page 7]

Zampieri Gabriele Speed'o'Meter v 1.0 https://github.com/gabbla/speedometer

Sheet: 7/7

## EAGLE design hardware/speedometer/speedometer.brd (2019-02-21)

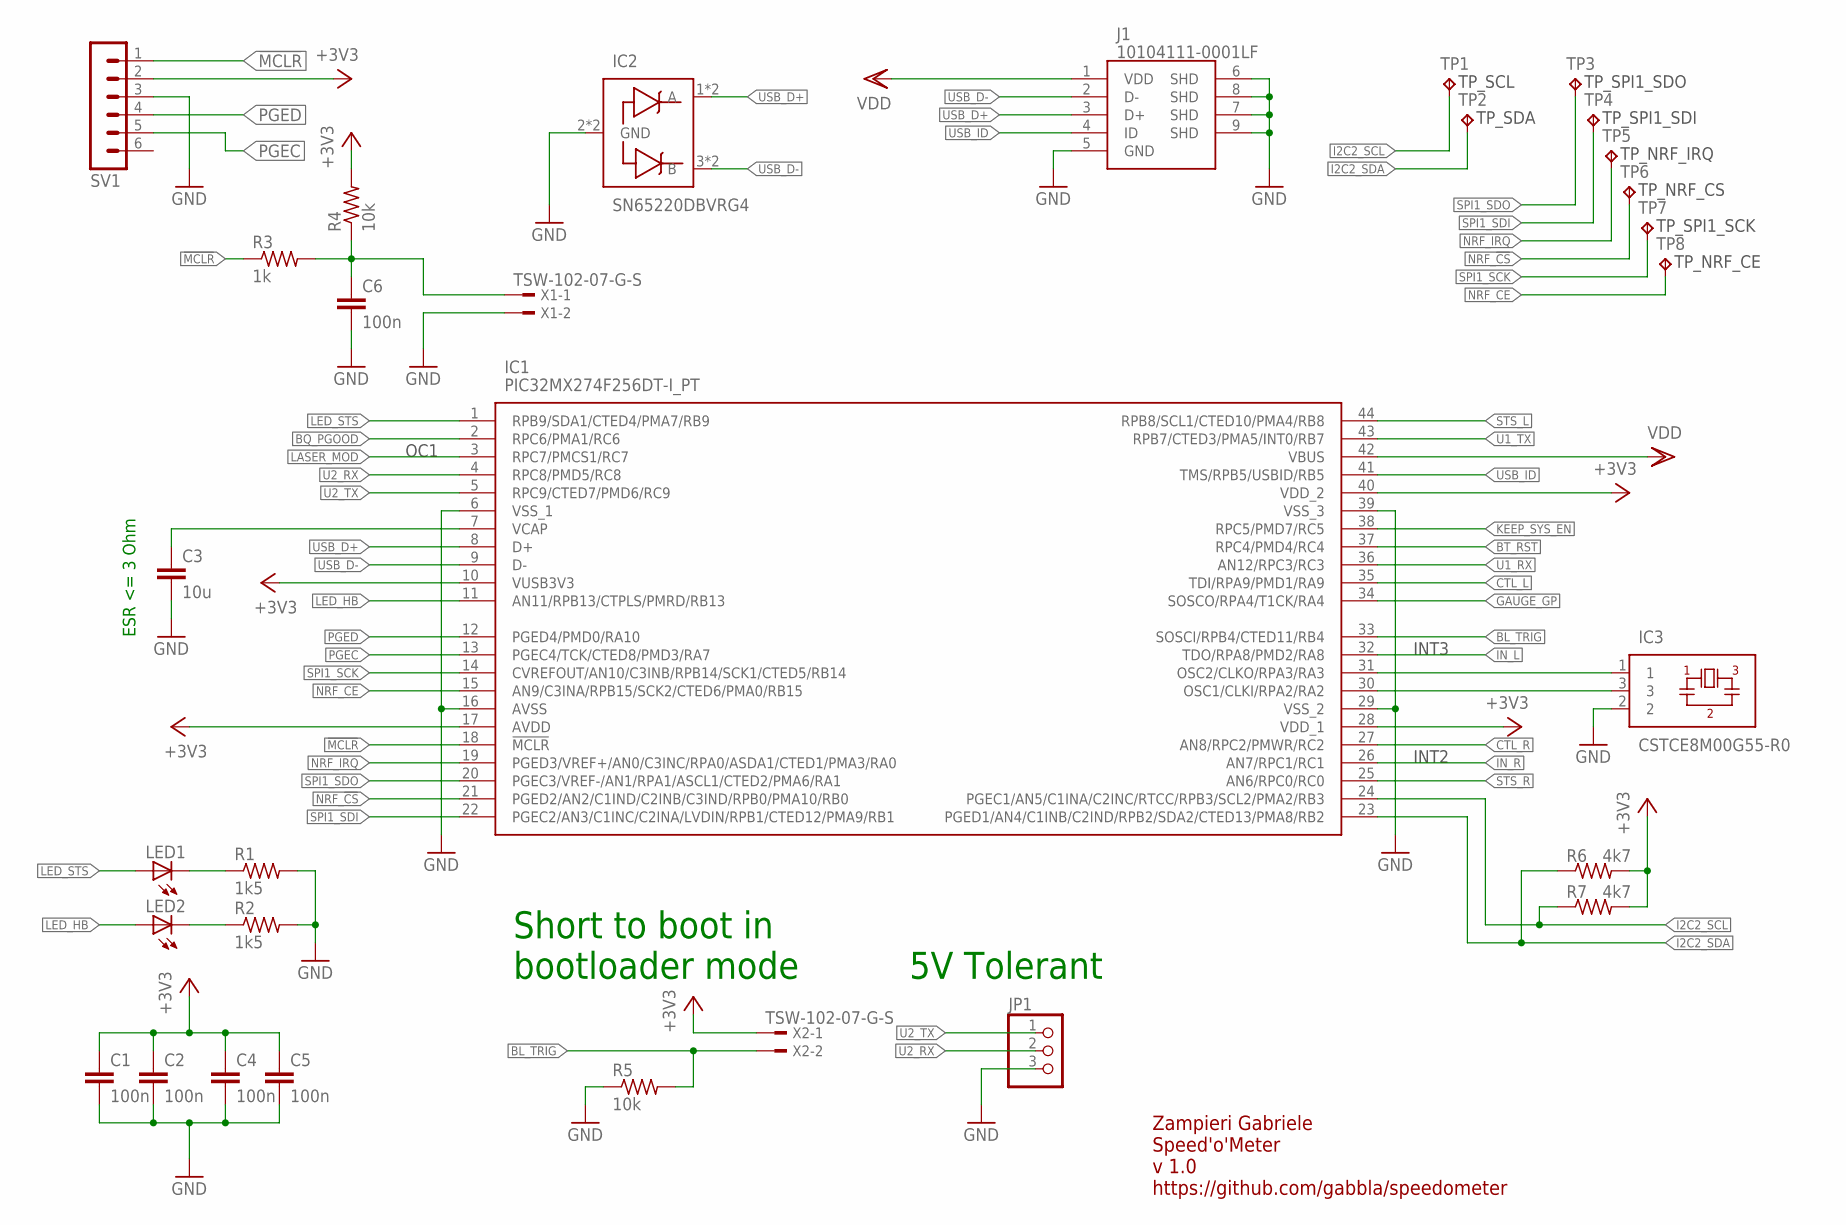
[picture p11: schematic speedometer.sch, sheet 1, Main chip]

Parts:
C1, C2, C4, C5, C6: 100n; C0603K
C3: 10u; C0805K
IC1: PIC32MX274F256DT-I_PT; QFP80P1200X1200X120-44N
IC2: SN65220DBVRG4; SOT95P280X145-6N
IC3: CSTCE8M00G55-R0; CSTCE_G
J1: 10104111-0001LF; MICRO_USB_A/B_TYPE_RECEPTACLE
JP1: PINHD-1X3; 1X03
LED1: LED3MM
LED2: LEDCHIPLED_0805; CHIPLED_0805
R1, R2: 1k5; R0603
R3: 1k; R0603
R4, R5: 10k; R0603
R6, R7: 4k7; R0603
SV1: MA06-1
TP1, TP2, TP3, TP4, TP5, TP6, TP7, TP8: TPB1,27; B1,27
X1, X2: TSW-102-07-G-S; TSW-102-XX-G-S

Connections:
!MCLR: IC1.18 (!MCLR), R3.1, SV1.1
+3V3: C1.1, C2.1, C4.1, C5.1, IC1.10 (VUSB3V3), IC1.17 (AVDD), IC1.28 (VDD_1), IC1.40 (VDD_2), R4.2, R6.2, R7.2, SV1.2, X2.1; also elsewhere on the board
BL_TRIG: IC1.33 (SOSCI/RPB4/CTED11/RB4), R5.2, X2.2
BQ_PGOOD: IC1.2 (RPC6/PMA1/RC6); also elsewhere on the board
BT_RST: IC1.37 (RPC4/PMD4/RC4); also elsewhere on the board
CTL_L: IC1.35 (TDI/RPA9/PMD1/RA9); also elsewhere on the board
CTL_R: IC1.27 (AN8/RPC2/PMWR/RC2); also elsewhere on the board
GAUGE_GP: IC1.34 (SOSCO/RPA4/T1CK/RA4); also elsewhere on the board
GND: C1.2, C2.2, C3.2, C4.2, C5.2, C6.2, IC1.6 (VSS_1), IC1.16 (AVSS), IC1.29 (VSS_2), IC1.39 (VSS_3), IC2.2 (GND), IC2.5 (GND), IC3.2, J1.5 (GND), J1.6 (SHD), J1.7 (SHD), J1.8 (SHD), J1.9 (SHD), JP1.3, R1.2, R2.2, R5.1, SV1.3, X1.2; also elsewhere on the board
I2C2_SCL: IC1.24 (PGEC1/AN5/C1INA/C2INC/RTCC/RPB3/SCL2/PM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), R7.1, TP1.TP; also elsewhere on the board
I2C2_SDA: IC1.23 (PGED1/AN4/C1INB/C2IND/RPB2/SDA2/CTED13/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), R6.1, TP2.TP; also elsewhere on the board
IN_L: IC1.32 (TDO/RPA8/PMD2/RA8); also elsewhere on the board
IN_R: IC1.26 (AN7/RPC1/RC1); also elsewhere on the board
KEEP_SYS_EN: IC1.38 (RPC5/PMD7/RC5); also elsewhere on the board
LASER_MOD: IC1.3 (RPC7/PMCS1/RC7); also elsewhere on the board
LED_HB: IC1.11 (AN11/RPB13/CTPLS/PMRD/RB13), LED2.A
LED_STS: IC1.1 (RPB9/SDA1/CTED4/PMA7/RB9), LED1.A
unnamed: LED1.K (C), R1.1
unnamed: IC1.31 (OSC2/CLKO/RPA3/RA3), IC3.1
unnamed: IC1.30 (OSC1/CLKI/RPA2/RA2), IC3.3
unnamed: C3.1, IC1.7 (VCAP)
unnamed: LED2.C, R2.1
unnamed: C6.1, R3.2, R4.1, X1.1
NRF_!CS: IC1.21 (PGED2/AN2/C1IND/C2INB/C3IND/RPB0/PMA10/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), TP6.TP; also elsewhere on the board
NRF_CE: IC1.15 (AN9/C3INA/RPB15/SCK2/CTED6/PMA0/RB15), TP8.TP; also elsewhere on the board
NRF_IRQ: IC1.19 (PGED3/VREF+/AN0/C3INC/RPA0/ASDA1/CTED1/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), TP5.TP; also elsewhere on the board
PGEC: IC1.13 (PGEC4/TCK/CTED8/PMD3/RA7), SV1.5
PGED: IC1.12 (PGED4/PMD0/RA10), SV1.4
SPI1_SCK: IC1.14 (CVREFOUT/AN10/C3INB/RPB14/SCK1/CTED5/RB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), TP7.TP; also elsewhere on the board
SPI1_SDI: IC1.22 (PGEC2/AN3/C1INC/C2INA/LVDIN/RPB1/CTED12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), TP4.TP; also elsewhere on the board
SPI1_SDO: IC1.20 (PGEC3/VREF-/AN1/RPA1/ASCL1/CTED2/PMA6/R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), TP3.TP; also elsewhere on the board
STS_L: IC1.44 (RPB8/SCL1/CTED10/PMA4/RB8); also elsewhere on the board
STS_R: IC1.25 (AN6/RPC0/RC0); also elsewhere on the board
U1_RX: IC1.36 (AN12/RPC3/RC3); also elsewhere on the board
U1_TX: IC1.43 (RPB7/CTED3/PMA5/INT0/RB7); also elsewhere on the board
U2_RX: IC1.4 (RPC8/PMD5/RC8), JP1.2
U2_TX: IC1.5 (RPC9/CTED7/PMD6/RC9), JP1.1
USB_D+: IC1.8 (D+), IC2.1 (A), IC2.6 (A), J1.3 (D+)
USB_D-: IC1.9 (D-), IC2.3 (B), IC2.4 (B), J1.2 (D-)
USB_ID: IC1.41 (TMS/RPB5/USBID/RB5), J1.4 (ID)
VDD: IC1.42 (VBUS), J1.1 (VDD); also elsewhere on the board

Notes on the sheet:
Zampieri Gabriele Speed'o'Meter v 1.0 https://github.com/gabbla/speedometer
ESR <= 3 Ohm
5V Tolerant
Short to boot in bootloader mode
OC1
INT2
INT3

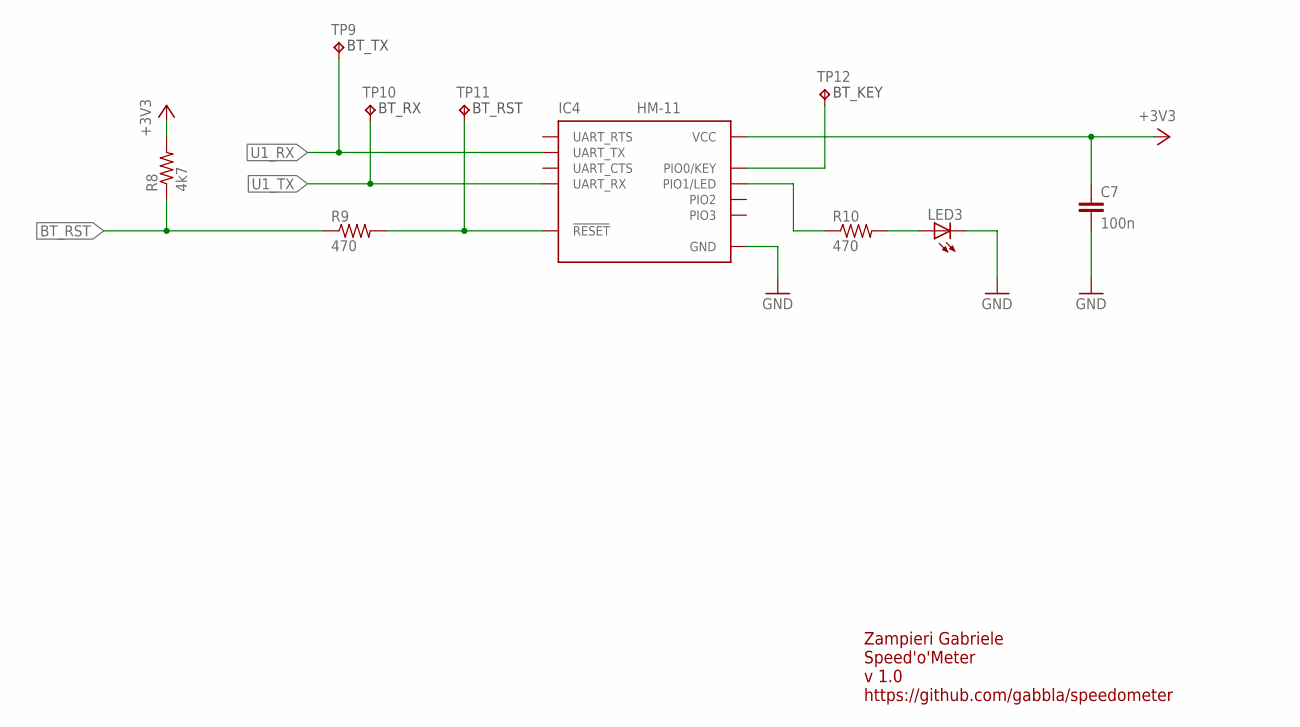
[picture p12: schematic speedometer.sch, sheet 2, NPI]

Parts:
C7: 100n; C0603K
IC4: HM-11
LED3: LED3MM
R8: 4k7; R0603
R9, R10: 470; R0603
TP9, TP10, TP11, TP12: TPB1,27; B1,27

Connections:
+3V3: C7.1, IC4.VCC, R8.2; also elsewhere on the board
BT_RST: R8.1, R9.1; also elsewhere on the board
GND: C7.2, IC4.GND, LED3.K (C); also elsewhere on the board
unnamed: IC4.RESETB (!RESET), R9.2, TP11.TP
unnamed: IC4.PIO0 (PIO0/KEY), TP12.TP
unnamed: IC4.PIO1 (PIO1/LED), R10.1
unnamed: LED3.A, R10.2
U1_RX: IC4.UART_TX, TP9.TP; also elsewhere on the board
U1_TX: IC4.UART_RX, TP10.TP; also elsewhere on the board

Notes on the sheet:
Zampieri Gabriele Speed'o'Meter v 1.0 https://github.com/gabbla/speedometer

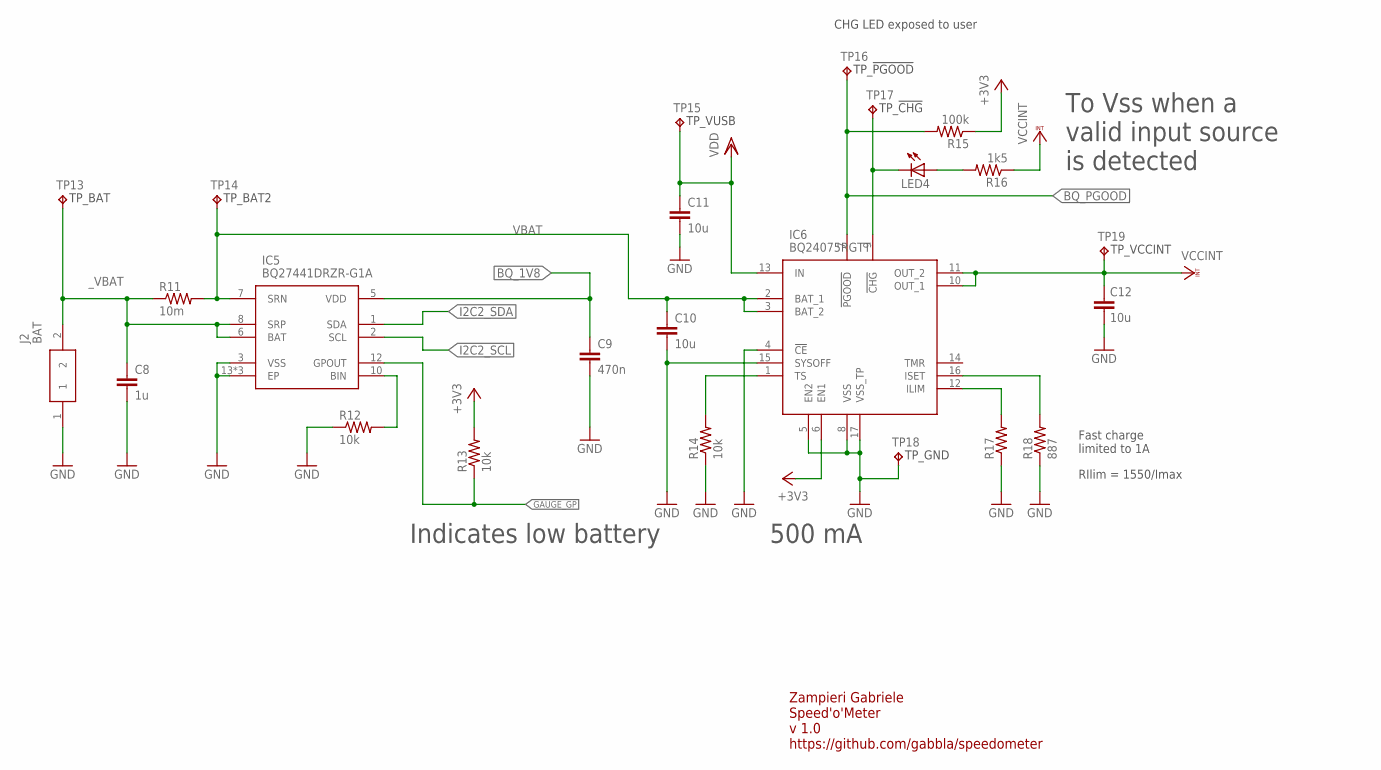
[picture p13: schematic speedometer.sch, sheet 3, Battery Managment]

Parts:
C8: 1u; C0603K
C9: 470n; C0603K
C10, C11, C12: 10u; C0805K
IC5: BQ27441DRZR-G1A; BQ27441DRZRG1A
IC6: BQ24075RGTT; QFN50P300X300X80-17N
J2: BAT; B2B-PH-SM4-TB
LED4: LED3MM
R11: 10m; R2512
R12, R13, R14: 10k; R0603
R15: 100k; R0603
R16: 1k5; R0603
R17: R-US_R0603; R0603
R18: 887; M0805
TP13, TP14, TP15, TP16, TP17, TP18, TP19: TPB1,27; B1,27

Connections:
!BAT_CHG: IC6.9 (!CHG), LED4.K (C), TP17.TP
+3V3: IC6.6 (EN1), R13.2, R15.1; also elsewhere on the board
BQ_1V8: C9.1, IC5.5 (VDD)
BQ_PGOOD: IC6.7 (!PGOOD), R15.2, TP16.TP; also elsewhere on the board
GAUGE_GP: IC5.12 (GPOUT), R13.1; also elsewhere on the board
GND: C8.2, C9.2, C10.2, C11.2, C12.2, IC5.3 (VSS), IC5.13 (EP), IC5.14 (EP), IC5.15 (EP), IC6.4 (!CE), IC6.5 (EN2), IC6.8 (VSS), IC6.15 (SYSOFF), IC6.17 (VSS_TP), J2.1, R12.1, R14.1, R17.1, R18.1, TP18.TP; also elsewhere on the board
I2C2_SCL: IC5.2 (SCL); also elsewhere on the board
I2C2_SDA: IC5.1 (SDA); also elsewhere on the board
unnamed: IC6.1 (TS), R14.2
unnamed: IC6.12 (ILIM), R17.2
unnamed: IC6.16 (ISET), R18.2
unnamed: LED4.A, R16.2
unnamed: IC5.10 (BIN), R12.2
VBAT: C10.1, IC5.7 (SRN), IC6.2 (BAT_1), IC6.3 (BAT_2), R11.2, TP14.TP
VCCINT: C12.1, IC6.10 (OUT_1), IC6.11 (OUT_2), R16.1, TP19.TP; also elsewhere on the board
VDD: C11.1, IC6.13 (IN), TP15.TP; also elsewhere on the board
_VBAT: C8.1, IC5.6 (BAT), IC5.8 (SRP), J2.2, R11.1, TP13.TP

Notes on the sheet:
CHG LED exposed to user
Zampieri Gabriele Speed'o'Meter v 1.0 https://github.com/gabbla/speedometer
500 mA
To Vss when a valid input source is detected
Indicates low battery
Fast charge limited to 1A
RIlim = 1550/Imax

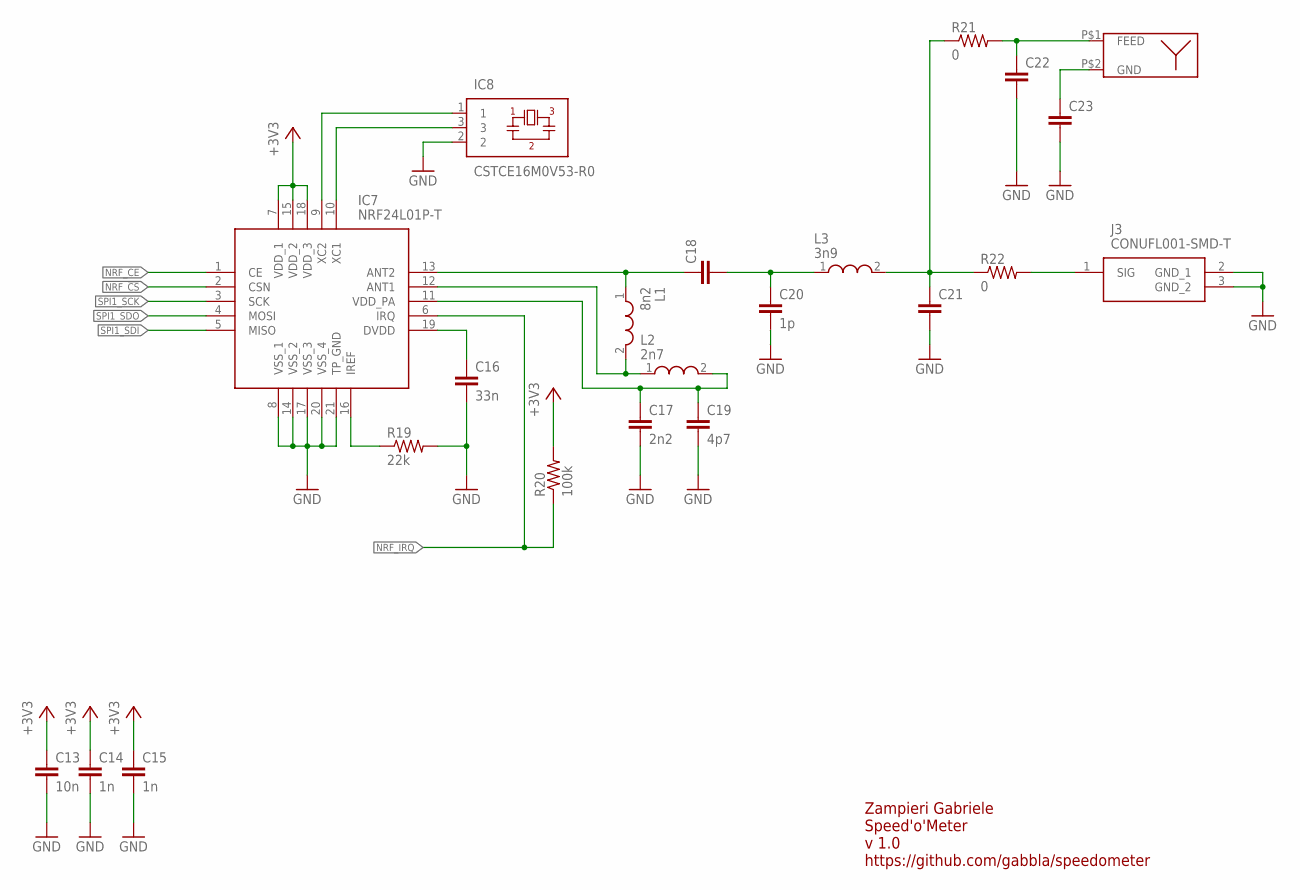
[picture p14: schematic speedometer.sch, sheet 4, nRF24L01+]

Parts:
ANT1: M310210
C13: 10n; C0603K
C14, C15: 1n; C0603K
C16: 33n; C0402K
C17: 2n2; C0402K
C18, C21, C22, C23: C-EUC0402K; C0402K
C19: 4p7; C0402K
C20: 1p; C0402K
IC7: NRF24L01P-T; QFN50P400X400X95-21N
IC8: CSTCE16M0V53-R0; CSTCE_G
J3: CONUFL001-SMD-T; CONUFL001-SMD
L1: 8n2; C0402K
L2: 2n7; C0402K
L3: 3n9; C0402K
R19: 22k; R0603
R20: 100k; R0603
R21, R22: 0; R0402

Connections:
+3V3: C13.1, C14.1, C15.1, IC7.7 (VDD_1), IC7.15 (VDD_2), IC7.18 (VDD_3), R20.2; also elsewhere on the board
GND: C13.2, C14.2, C15.2, C16.2, C17.2, C19.2, C20.2, C21.2, C22.2, C23.2, IC7.8 (VSS_1), IC7.14 (VSS_2), IC7.17 (VSS_3), IC7.20 (VSS_4), IC7.21 (TP_GND), IC8.2, J3.2 (GND_1), J3.3 (GND_2), R19.2; also elsewhere on the board
unnamed: C18.2, C20.1, L3.1
unnamed: C21.1, L3.2, R21.1, R22.1
unnamed: IC7.9 (XC2), IC8.1
unnamed: J3.1 (SIG), R22.2
unnamed: IC7.16 (IREF), R19.1
unnamed: C16.1, IC7.19 (DVDD)
unnamed: IC7.10 (XC1), IC8.3
unnamed: C18.1, IC7.13 (ANT2), L1.1
unnamed: IC7.12 (ANT1), L1.2, L2.1
unnamed: C17.1, C19.1, IC7.11 (VDD_PA), L2.2
unnamed: ANT1.P$2 (GND), C23.1
unnamed: ANT1.P$1 (FEED), C22.1, R21.2
NRF_!CS: IC7.2 (CSN); also elsewhere on the board
NRF_CE: IC7.1 (CE); also elsewhere on the board
NRF_IRQ: IC7.6 (IRQ), R20.1; also elsewhere on the board
SPI1_SCK: IC7.3 (SCK); also elsewhere on the board
SPI1_SDI: IC7.5 (MISO); also elsewhere on the board
SPI1_SDO: IC7.4 (MOSI); also elsewhere on the board

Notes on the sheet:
Zampieri Gabriele Speed'o'Meter v 1.0 https://github.com/gabbla/speedometer

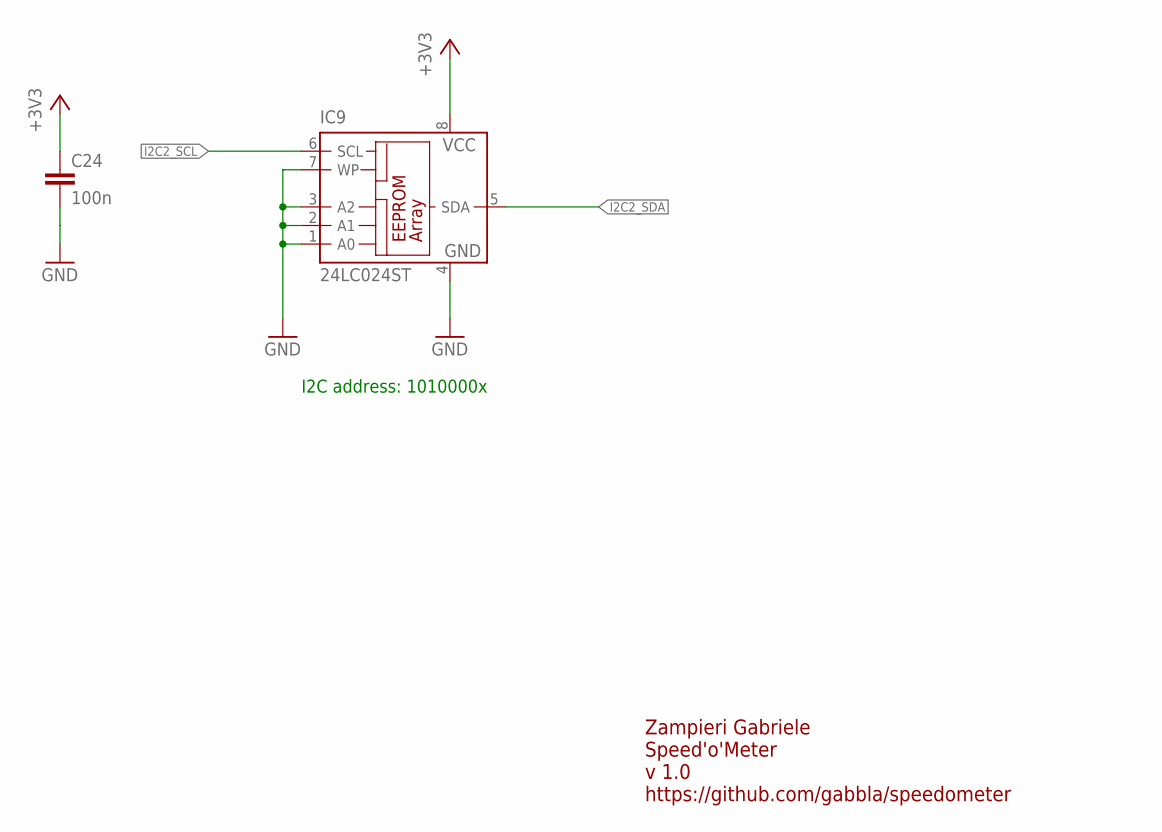
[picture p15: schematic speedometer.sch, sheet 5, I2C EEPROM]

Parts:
C24: 100n; C0603K
IC9: 24LC024ST; TSSOP8

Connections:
+3V3: C24.1, IC9.8 (VCC); also elsewhere on the board
GND: C24.2, IC9.1 (A0), IC9.2 (A1), IC9.3 (A2), IC9.4 (GND), IC9.7 (WP); also elsewhere on the board
I2C2_SCL: IC9.6 (SCL); also elsewhere on the board
I2C2_SDA: IC9.5 (SDA); also elsewhere on the board

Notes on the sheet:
I2C address: 1010000x
Zampieri Gabriele Speed'o'Meter v 1.0 https://github.com/gabbla/speedometer

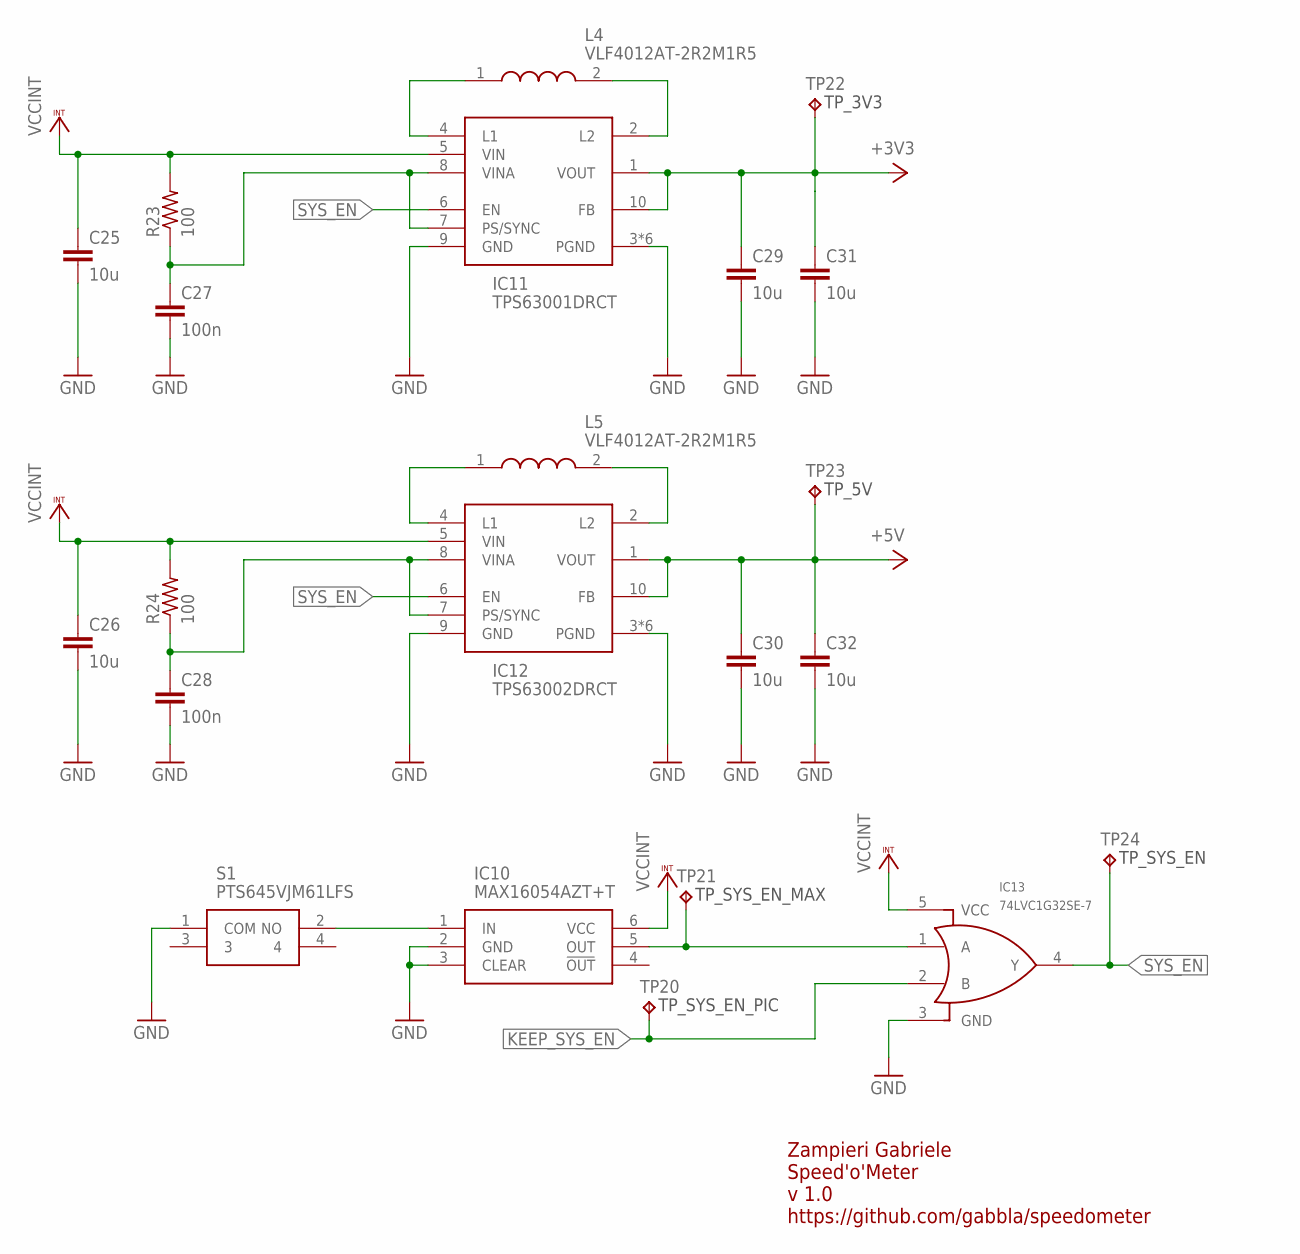
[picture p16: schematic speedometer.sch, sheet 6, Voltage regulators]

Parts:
C25, C26, C29, C30, C31, C32: 10u; C0805K
C27, C28: 100n; C0603K
IC10: MAX16054AZT+T; SOT95P275X110-6N
IC11: TPS63001DRCT; SON50P300X300X100-11N
IC12: TPS63002DRCT; SON50P300X300X100-11N
IC13: 74LVC1G32SE-7; SOT353
L4, L5: VLF4012AT-2R2M1R5; LPS3015
R23, R24: 100; R0603
S1: PTS645VJM61LFS
TP20, TP21, TP22, TP23, TP24: TPB1,27; B1,27

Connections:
+3V3: C29.1, C31.1, IC11.1 (VOUT), IC11.10 (FB), TP22.TP; also elsewhere on the board
+5V: C30.1, C32.1, IC12.1 (VOUT), IC12.10 (FB), TP23.TP; also elsewhere on the board
GND: C25.2, C26.2, C27.2, C28.2, C29.2, C30.2, C31.2, C32.2, IC10.2 (GND), IC10.3 (CLEAR), IC11.3 (PGND), IC11.9 (GND), IC11.11 (PGND), IC11.EP1 (PGND), IC11.EP2 (PGND), IC11.EP3 (PGND), IC11.EP4 (PGND), IC12.3 (PGND), IC12.9 (GND), IC12.11 (PGND), IC12.EP1 (PGND), IC12.EP2 (PGND), IC12.EP3 (PGND), IC12.EP4 (PGND), IC13.3 (GND), S1.1 (COM); also elsewhere on the board
KEEP_SYS_EN: IC13.2 (B), TP20.TP; also elsewhere on the board
MAX_SYS_ON: IC10.5 (OUT), IC13.1 (A), TP21.TP
unnamed: IC11.4 (L1), L4.1
unnamed: IC11.2 (L2), L4.2
unnamed: IC10.1 (IN), S1.2 (NO)
unnamed: IC12.4 (L1), L5.1
unnamed: C27.1, IC11.7 (PS/SYNC), IC11.8 (VINA), R23.1
unnamed: IC12.2 (L2), L5.2
unnamed: C28.1, IC12.7 (PS/SYNC), IC12.8 (VINA), R24.1
SYS_EN: IC11.6 (EN), IC12.6 (EN), IC13.4 (Y), TP24.TP
VCCINT: C25.1, C26.1, IC10.6 (VCC), IC11.5 (VIN), IC12.5 (VIN), IC13.5 (VCC), R23.2, R24.2; also elsewhere on the board

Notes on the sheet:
Zampieri Gabriele Speed'o'Meter v 1.0 https://github.com/gabbla/speedometer

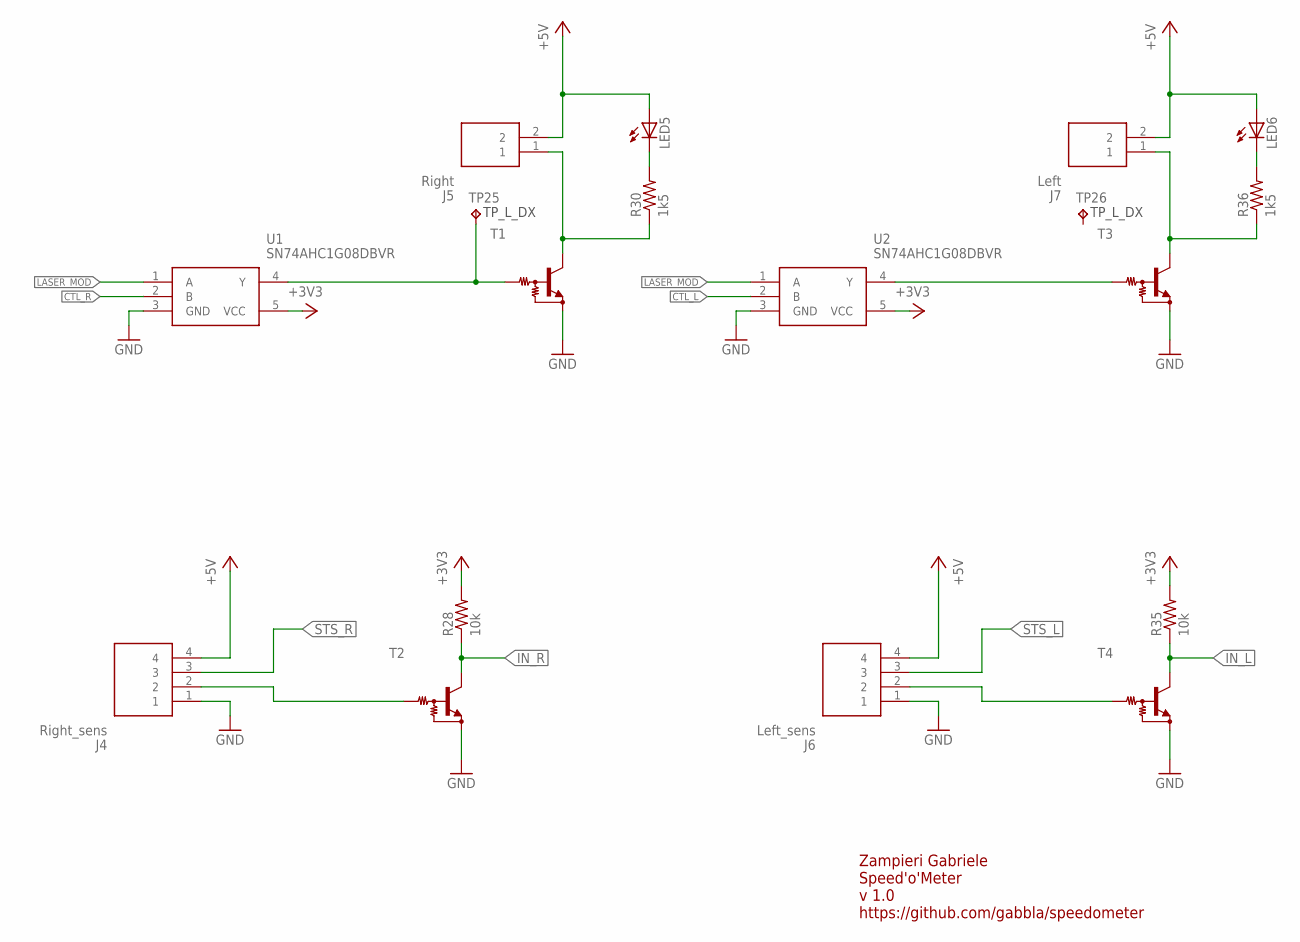
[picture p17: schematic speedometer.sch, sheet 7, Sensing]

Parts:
J4: Right_sens; SHDR4W64P0X250_1X4_1240X575X70
J5: Right; SHDR2W64P0X250_1X2_740X575X700
J6: Left_sens; SHDR4W64P0X250_1X4_1240X575X70
J7: Left; SHDR2W64P0X250_1X2_740X575X700
LED5, LED6: LEDCHIP-LED0805; CHIP-LED0805
R28, R35: 10k; R0603
R30, R36: 1k5; R0603
T1, T2, T3, T4: MUN2214T1-NPN_DRIVER-SC59-BEC; SC59-BEC
TP25, TP26: TPB1,27; B1,27
U1, U2: SN74AHC1G08DBVR; SOT95P280X145-5N

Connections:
+3V3: R28.2, R35.2, U1.5 (VCC), U2.5 (VCC); also elsewhere on the board
+5V: J4.4, J5.2, J6.4, J7.2, LED5.A, LED6.A; also elsewhere on the board
CTL_L: U2.2 (B); also elsewhere on the board
CTL_R: U1.2 (B); also elsewhere on the board
GND: J4.1, J6.1, T1.E, T2.E, T3.E, T4.E, U1.3 (GND), U2.3 (GND); also elsewhere on the board
IN_L: R35.1, T4.C; also elsewhere on the board
IN_R: R28.1, T2.C; also elsewhere on the board
LASER_MOD: U1.1 (A), U2.1 (A); also elsewhere on the board
unnamed: J7.1, R36.1, T3.C
unnamed: LED6.C, R36.2
unnamed: T3.B, U2.4 (Y)
unnamed: J4.2, T2.B
unnamed: J6.2, T4.B
unnamed: J5.1, R30.1, T1.C
unnamed: LED5.C, R30.2
unnamed: T1.B, TP25.TP, U1.4 (Y)
STS_L: J6.3; also elsewhere on the board
STS_R: J4.3; also elsewhere on the board

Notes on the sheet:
Zampieri Gabriele Speed'o'Meter v 1.0 https://github.com/gabbla/speedometer

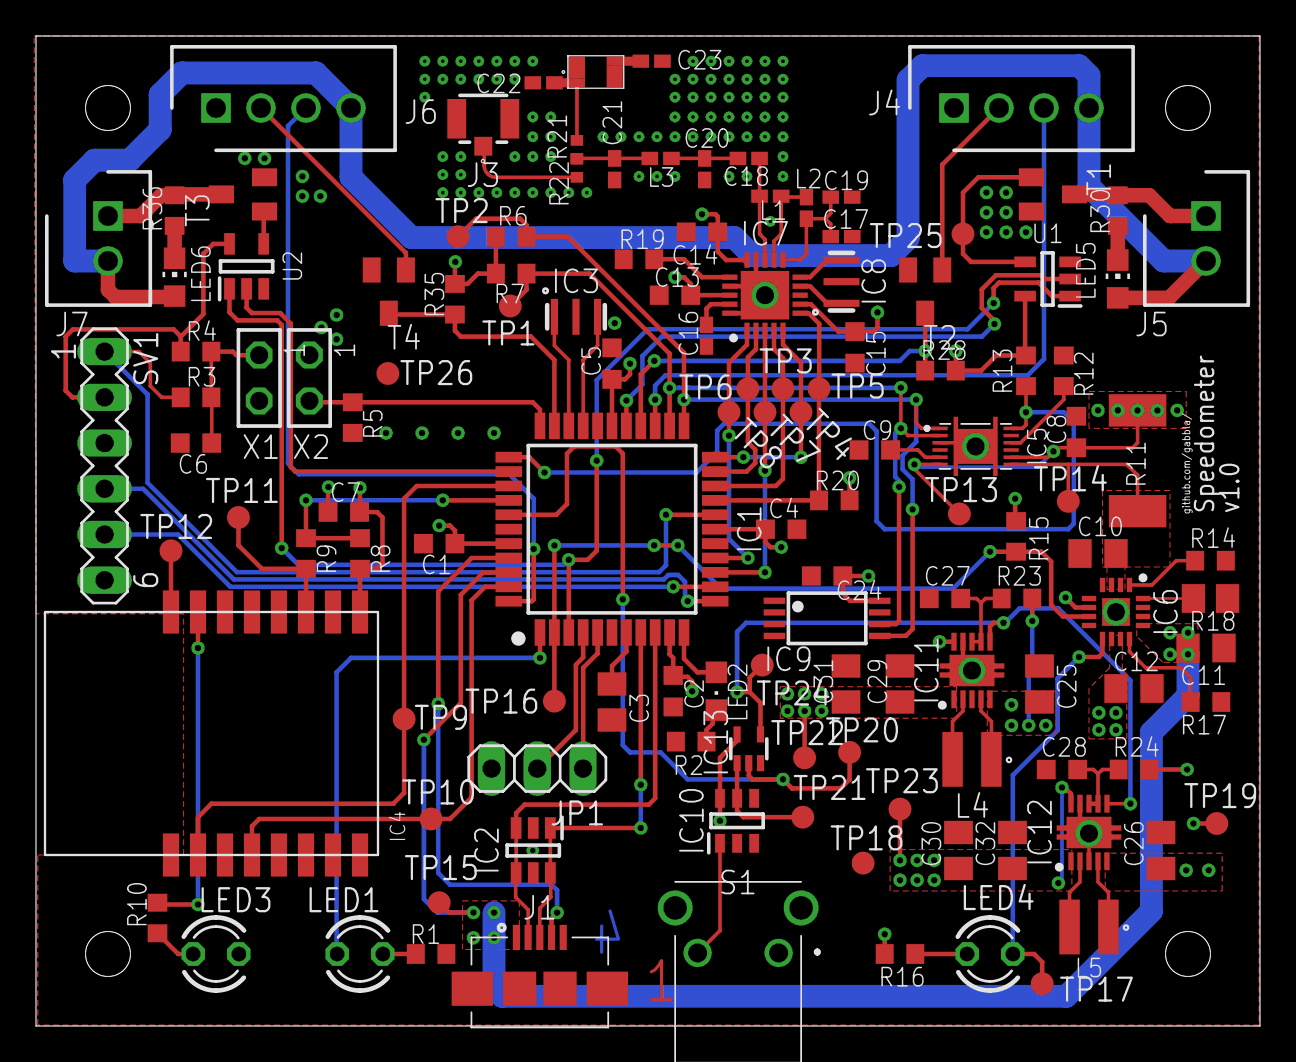
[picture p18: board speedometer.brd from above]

Board: 4 copper layers, 68.0 x 55.0 mm, 129 parts (1 on the bottom side), 85 nets.

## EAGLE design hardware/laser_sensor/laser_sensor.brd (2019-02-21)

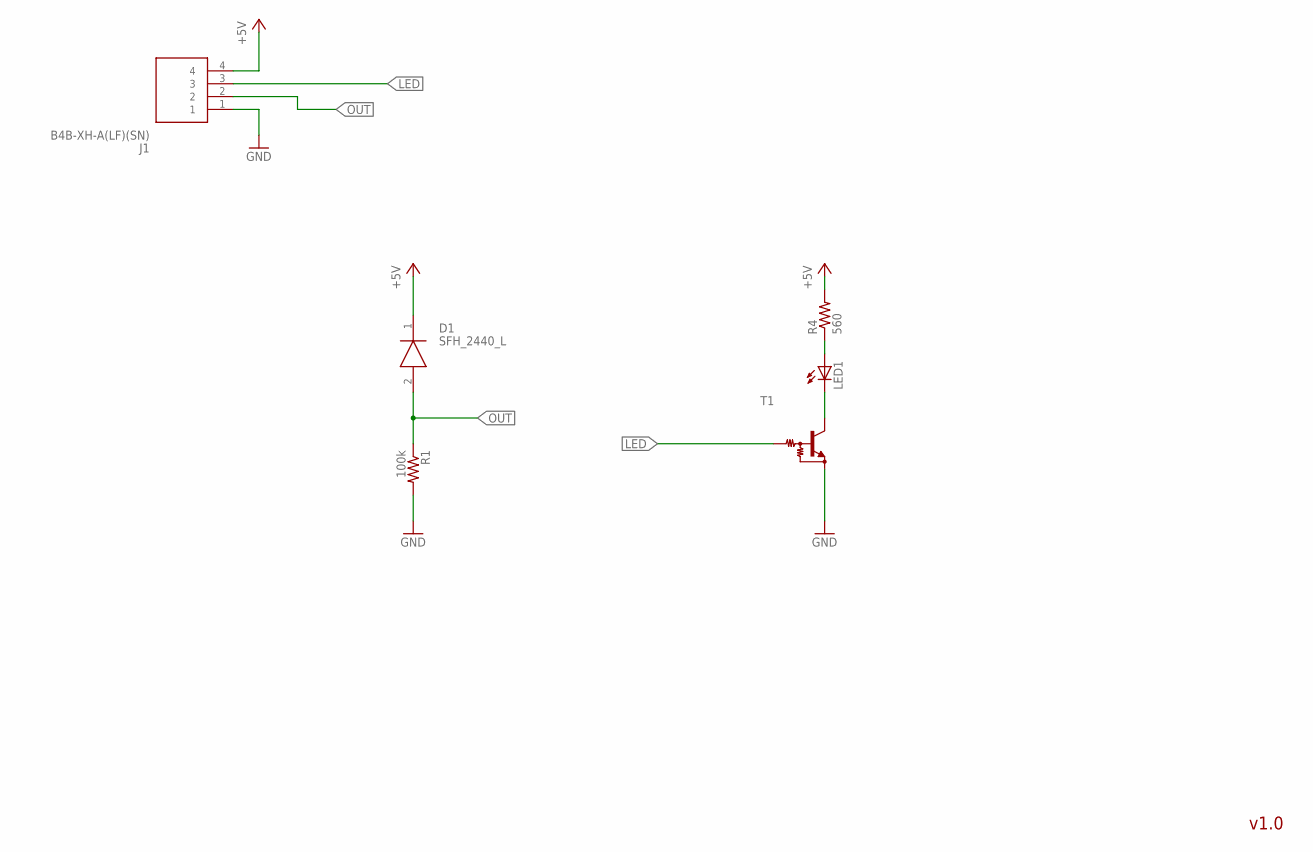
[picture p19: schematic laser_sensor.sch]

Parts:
D1: SFH_2440_L; SFH2440L
J1: B4B-XH-A(LF)(SN); SHDR4W64P0X250_1X4_1240X575X70
LED1: LED3MM
R1: 100k; R0603
R4: 560; R0603
T1: MUN2214T1-NPN_DRIVER-SC59-BEC; SC59-BEC

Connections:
+5V: D1.1 (ANODE), J1.4, R4.2
GND: J1.1, R1.2, T1.E
LED: J1.3, T1.B
unnamed: LED1.A, R4.1
unnamed: LED1.K (C), T1.C
OUT: D1.2 (CATHODE), J1.2, R1.1

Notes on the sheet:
v1.0

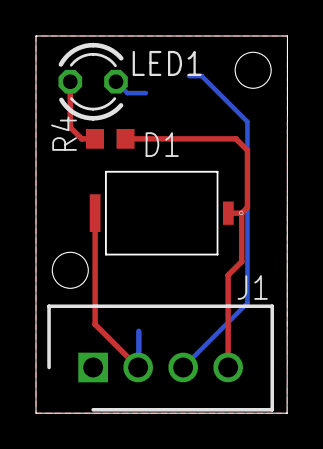
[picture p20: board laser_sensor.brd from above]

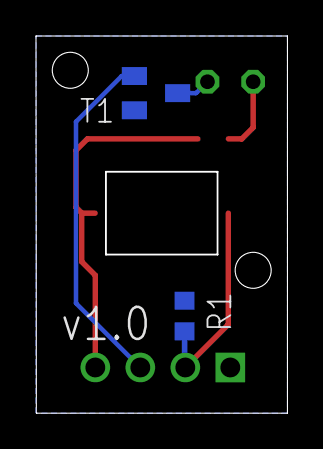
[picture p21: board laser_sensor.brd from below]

Board: 2 copper layers, 14.0 x 21.0 mm, 6 parts (2 on the bottom side), 6 nets.

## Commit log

2018-07-07 First hardwere draft
    [speedometer.sch]
2018-07-15 - Eagle libraries added - Initial import
    [speedometer.sch]
2018-07-18 Pin functions and number updated
2018-08-09 Added debug uart Minor changes
2018-08-09 IAR stuff.. to lazy to track them. I won't use them anymore
    [speedometer.sch]
2018-08-10 Added regexp to exclude Eagle cad temp files
2018-08-10 PIC added
    [speedometer.sch]
2018-08-12 Laser ctl pins are now on I/O Expander
2018-08-13 Vertical switch added
2018-08-13 Schema version 1.0alpha
    [speedometer.sch]
2018-08-13 Library added
    [speedometer.brd]
2018-08-14 Ignoring also Eagle temp board files
2018-08-14 Most of the work is done. Fixing ground planes and power paths
    [speedometer.brd, speedometer.sch]
2018-08-14 Ignoring board tmp files
2018-08-14 Routing is done. Waiting a check from a Sandro
    [speedometer.brd, speedometer.sch]
2018-08-14 Laser sensor project created
    [laser_sensor.sch]
2018-08-15 First complete route for laser sensor
    [laser_sensor.brd, laser_sensor.sch]
2018-08-15 Laser sensor gerber added
    [copper_top.gbr, drills.xln, gerber_job.gbrjob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]
2018-08-16 Board images added
2018-08-16 laser sensor gerber updated
    [laser_sensor.brd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]
2018-08-16 CAM process to generate gerber for sensor added
2018-08-16 Updated sensor gerber
    [copper_bottom.gbr, silkscreen_bottom.gbr, soldermask_bottom.gbr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]
2018-08-16 Added main board gerber files
    [copper_bottom.gbr, copper_top.gbr, drills.xln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]
2018-08-16 Added cam file to generate main board gerber
2018-08-19 TPS6300x inductors changed
    [speedometer.brd, speedometer.sch]
2018-08-19 Main board gerber updated
    [copper_bottom.gbr, copper_top.gbr, drills.xln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]
2018-08-19 Main board BOM added
    [speedometer.csv, speedometer.ods]
2018-08-19 Laser sensor BOM added
    [laser_sensor.csv, laser_sensor.ods]
2018-08-19 Main board schematic pdf added
2018-08-20 Fixed some stuff with Sandro's help. Main board gerber updated
    [speedometer.brd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]
2018-08-20 Schematics pdf prints added
2018-08-20 Version added
    [speedometer.sch]
2018-09-04 Added revision info. PDF updated
    [speedometer.sch]
2018-09-04 Image updated with produced PCB gerbers
2018-11-02 Added laser support model
    [sensor_laser_support.f3d]
2018-11-02 Added gitignore
    [laser_sensor.brd, laser_sensor.csv, laser_sensor.ods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]
2018-11-02 Added sensor support 3D model
    [sensor_laser_support.f3d]
2018-11-02 BOM added
    [laser_sensor.csv, laser_sensor.ods, speedometer.csv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]
2018-11-02 Hardware sync
    [laser_sensor.brd, laser_sensor.sch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]
2018-11-15 Fixed diode (#8) and battery polarity (#5)
    [speedometer.brd, speedometer.sch]
2018-11-15 Removed I/O expander
    [speedometer.brd, speedometer.sch]
2018-11-15 Removed selectable voltage on laser connectors
    [speedometer.brd, speedometer.sch]
2018-11-15 Removed MCP2200
    [speedometer.brd, speedometer.sch]
2018-11-15 Added BQ27441, still wip
    [speedometer.brd, speedometer.sch]
2018-11-16 Switched HM10 with a more compact HM11
    [speedometer.brd, speedometer.sch]
2018-11-19 New symbol for usb connector
2018-11-19 PIC32MX274F256 added
    [speedometer.brd, speedometer.sch]
2018-11-20 Symbol pin moved
2018-11-20 PIC pin assigned, LiPo gauge connected
    [speedometer.brd, speedometer.sch]
2018-11-20 Some stuff added
    [speedometer.brd, speedometer.sch]
2018-11-21 Minor stuff
    [speedometer.brd, speedometer.sch]
2018-11-26 Laser ctl logic added
    [speedometer.brd, speedometer.sch]
2018-11-30 mirror support added
    [mirror_support .f3d]
2018-12-18 laser resize 12 -> 6 mm
    [sensor_laser_support.f3d]
2019-01-02 notes added
    [speedometer.brd, speedometer.sch]
2019-01-02 fixed led off while charging the board in off state
    [speedometer.brd, speedometer.sch]
2019-01-02 new board dimension
    [speedometer.brd]
2019-01-02 part renumbered
    [speedometer.brd, speedometer.sch]
2019-01-02 pcb: power routed
    [speedometer.brd, speedometer.sch]
2019-01-05 wip, mostly done
    [speedometer.brd, speedometer.sch]
2019-01-18 new board 4layer
    [speedometer.brd]
2019-01-18 new outline size
    [speedometer.brd]
2019-01-18 new size 68x55
    [speedometer.brd]
2019-01-18 power added
    [speedometer.brd, speedometer.sch]
2019-01-19 antenna draft
2019-01-19 switch centered
2019-01-23 first layout draft
    [speedometer.brd, speedometer.sch]
2019-01-23 sensor redesign
    [laser_sensor.brd, laser_sensor.sch]
2019-01-24 dimension fix according to the manufacturer
    [laser_sensor.brd, laser_sensor.sch]
2019-02-08 aligned with GF suggestion, waiting approval
    [speedometer.brd, speedometer.sch]
2019-02-12 part renumber
    [speedometer.brd, speedometer.sch]
2019-02-12 gerber added
2019-02-12 gerber update with labels
    [laser_sensor.brd]
2019-02-12 updated pdf added
    [speedometer.sch]
2019-02-12 updated pdf added for sensor
    [laser_sensor.sch]
2019-02-13 bom added (generated from eagle)
    [bom_laser_sensor.csv, speedometer_bom.csv]
2019-02-21 changed some transistors
    [speedometer.brd, speedometer.sch]
2019-02-21 changed 887 package to 0805
    [speedometer.brd, speedometer.csv, speedometer.sch]
